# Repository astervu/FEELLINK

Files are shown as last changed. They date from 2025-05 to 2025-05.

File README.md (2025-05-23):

# FEELLINK

LOGO fin

*Met FEELLINK kan een leerling uit een autiklas zijn emoties en gevoelens makkelijk en laagdrempelig communiceren met de leerkracht om zo conflicten, ongemakken en frustraties bij leerlingen in de klas makkelijker te begrijpen en op te lossen. Ook helpt FEELLINK bij zelfregulatie van de leerling door middel van fidgeting en stimming.* 

*Projectteam: Aster Vuylsteke, Aimé Van Alboom*

*Datum: 21/05/2025*

## Samenvatting
Kinderen met ASS hebben vaak moeite om over hun emoties en gevoelens te communiceren. Ze ervaren een hoge drempel om dit te doen of communiceren hun behoeften niet duidelijk, wat kan leiden tot conflicten, ongemak en frustratie.

Om dit probleem te onderzoeken, observeerden we een type 9-klas en voerden we drie interviews uit: met een persoon met ASS, een leerling met ASS en een leerkracht met ervaring in autiklassen. Deze inzichten benadrukten de noodzaak van een laagdrempelig communicatiemiddel dat ook helpt bij zelfregulatie.

Onze oplossing is een slimme fidget met een ingebouwd apparaatje waarmee leerlingen hun emoties kunnen aangeven via iconen (zoals emoji’s). De leerkracht kan in een bijbehorende app de status van elke leerling bekijken.

Het ingebouwde apparaatje maakt communicatie eenvoudiger, omdat de interactie met het apparaat minder confronterend is dan directe mens-mens communicatie. De visuele iconen bevorderen de zelfexpressie en verbeteren het begrip van de eigen emotie bij de leerling. De fidget helpt met zelfregulatie, focus en het verminderen van angst en stress door tactiele stimulatie. Bovendien merkt de omgeving niet dat de leerling iets communiceert, wat extra comfort biedt. Dit zorgt voor een rustigere en meer begripvolle leeromgeving waarin leerlingen beter ondersteund worden.

render feellink !(met knoppen)

## Introductie
Er zijn al verschillende hulpmiddelen beschikbaar die kinderen met autisme spectrum stoornis (ASS) ondersteunen bij het verbeteren van hun communicatieve vaardigheden. Echter, er is nog geen hulpmiddel dat hen direct helpt om hun emoties te identificeren en te communiceren op het moment dat dit nodig is, zonder dat ze een drempel moeten overschrijden die hen kwetsbaar maakt voor de aandacht van andere leerlingen. Dit is vooral problematisch in de klas, waar snel overprikkelde leerlingen vaak niet in staat zijn om effectief te communiceren over hun gevoelens, wat hun welzijn en hun vermogen om zich te concentreren verstoort.

ASS is een spectrumstoornis, wat betekent dat de kenmerken en intensiteit ervan sterk variëren tussen individuen. Veelvoorkomende uitdagingen zijn onder andere moeite met sociale interactie, het herkennen van emoties, en het interpreteren van verbale en non-verbale communicatie. Deze moeilijkheden kunnen leiden tot conflicten in de klas, vaak ontstaan door miscommunicatie of zelfs geen communicatie tussen leerlingen of tussen leerlingen en leerkrachten. Dit kan resulteren in verloren tijd tijdens de les of verminderde prestaties, doordat de leerling zich ongemakkelijk en onbegrepen voelt.

Dit onderzoek richt zich op de ontwikkeling van een product dat kinderen met ASS helpt bij drie cruciale aspecten: communicatie, emotionele regulatie en focus. Het doel is een oplossing te bieden die hen helpt hun emoties op een toegankelijke manier te uiten, zonder dat dit extra stress veroorzaakt. Door dit hulpmiddel te integreren in de klas kunnen misverstanden worden verminderd, kunnen leerlingen zich beter concentreren en kunnen conflicten sneller worden opgelost, wat uiteindelijk bijdraagt aan een effectievere leerervaring.

## Methodologie
Doorheen het ontwerpproces hebben we gewerkt met een gestructureerde aanpak die steeds de gebruiker centraal stelde in het ontwerpproces. Zo hebben we zoveel mogelijk de gebruikersdoelgroep aangesproken om hen te betrekken in het ontwerpproces. Ook konden we zo het product zo gebruikersvriendelijk mogelijk maken.

In de exploratiefase zijn we eerst en vooral begonnen met onderzoek naar de gebruiker. Aangezien de gebruikers vaak specifieke noden kunnen hebben, was het belangrijk om te gaan onderzoeken waar gebruikers veel belang aan hechten. Hiermee ging gepaard dat we een goed doordachte identificatie van het probleem opstelden alsook de analyse ervan. Dit deden we aan de hand van literatuuronderzoek, gebruiker interviews, expert interviews en een ‘day in the life’.  Het ondervonden probleem is dan verder onderzocht geweest, dit aan de hand van literatuuronderzoek en benchmarking over bestaande systemen die men gebruikt bij kinderen met ASS.

In de definitiefase vertrokken we vanuit een storyboard om ons te verdiepen in de noden van de gebruiker. In deze fase hebben we zowel fysieke als digitale prototypes gemaakt die we getest hebben bij onze gebruikersdoelgroep in 3 design waves. Zo moesten we het concept opsplitsen in twee delen met twee verschillende gebruikers, de leerling en de leerkracht. De eerste 2 design waves hebben we besteed aan het zo goed mogelijk voldoen aan de eisen en noden van de leerling. Dit deden we aan de hand van usertesting en userinterviews tijdens deze test om hun eerlijke mening te krijgen. Voor het tweede deel van het concept, de tool voor de leerkrachten, hebben we een enquête gemaakt om insteek te krijgen van de leerkrachten in het maken van de interface van deze tool. Dit deden we aan de hand van vragen te stellen over low fidelity interfaces die we enkele simpele gebruiksinteracties hadden toegekend.

Hierna is er over gegaan naar developfase 1. In deze fase is er begonnen met het onderzoeken van de integratie van het product in de klas als ook onderzoek naar de ergonomie van het product. Dit is vooral gebeurd aan de hand van A/B testing van prototypes gebaseerd op data uit antropometrische tabellen. Zo kon de plaats van het product in de klas worden vastgelegd en ook de grootte van het product en de grootte van de knoppen op de fysieke interface. Daarnaast is er ook gekeken naar de integratie van het emotieaanduidsysteem tot een product samen met de fidget. Dit is gebeurd aan de hand van een beslissingsmatrix met vooraf opgestelde succescriteria en aan de hand van de verschillende mentale modellen die de leerlingen opbouwden bij enkele conceptschetsen. Ook is er een korte peiling gebeurd om te achterhalen met welke fidgets de kinderen het meest vertrouwd zijn.

In developfase 2 vertrokken we vanuit de vraag het product te optimaliseren vanuit het standpunt van de leerkracht. Dit is gebeurd aan de hand van interviews met leerkrachten waarin er gefocust werd op: de meldingen die de leerkracht zou ontvangen bij emotieverandering, dataopvolging van de leerling, het apparaat waarop de leerkracht de stand van de leerling kan zien en eventuele obstakels die door ons gemist waren. Om deze mogelijke obstakels te identificeren is er gebruik gemaakt van een storyboard. Ook is er onderzocht hoe we het emotieaanduidsysteem kunnen integreren tot een product samen met het fidget systeem, dit gebeurde aan de hand van A/B/C-testing waarna de pro's en cons van de twee favorieten afgewogen werden tegen elkaar. Daarnaast is er ook nog even verder ingepikt op de ergonomietesten uit develop 1, waarbij er maximaal gewichtttesten zijn gebeurd.

In de laatste fase, developfase 3, is er onderzocht hoe ervoor kan gezorgd worden dat de leerlingen de tool willen en blijven gebruiken. Dit is gebeurd aan de hand van theoretische modellen en een beperkte literatuurstudie. Hierna volgde een PESTEL analyse door studenten uit het vak De kennismaatschappij en ICT die vanuit een buitenstaander standpunt feedback en tips gaven. Daarnaast is er ook een co-design test gebeurd met de leerlingen waarbij ze zelf konden beslissen in welke volgorde de emotieknoppen moeten staan op de interface. In deze fase is er ook een lessimulatie met een (zo goed als) werkend prototype gebeurd. Hierbij werd er gekeken naar de user experience bij verschillende feedbackmethoden. Om daarnaast ook de algemene integratie in de klas te simuleren is er gebruik gemaakt van Wizard of Oz-testing, waarbij telkens als de leerling een emotie aanduidde, deze werd veranderd op een gedeelde interface met de leerkracht en de leerkracht dan een trilling kreeg doorgestuurd. Na deze simulatie kregen de leerlingen en de leerkrachten een vragenlijst om de user experience beter te kunnen inschatten.

Na elke testfase werd er een grondige analyse uitgevoerd om de belangrijkste ontwerpvereisten te identificeren. Deze vereisten werden zowel gebruikt als richtlijn doorheen het project maar zijn ook eisen die moeten aangehouden worden bij verdere ontwikkeling van het product.



## Discovery

### Doestellingen
In de discoveryfase onderzoeken we de onderzoeksvraag: Hoe kan de leer- en schoolervaring voor kinderen met autisme aangenamer gemaakt worden? Voordat we deze vraag kunnen beantwoorden moeten we volgende stappen doorlopen:

  <ins>  1.	Onderzoek naar de doelgroep</ins>

Hier gingen we vooral op zoek naar wat het betekent om ASS te hebben, met een specifieke focus op kinderen. Hierdoor krijgen we meer inzicht in hun behoeften en uitdagingen.

   <ins>  2.	Probleemidentificatie en analyse</ins> 

We onderzoeken waar kinderen met ASS de meeste moeite mee hebben in een klasomgeving. Welke activiteiten op school leveren het meeste problemen op en wat heeft dit als gevolg op hun resultaten en schoolervaring? Zijn de kinderen bewust van hun eigen emotie en in welke mate kunnen ze die reguleren of communiceren?

  <ins>  3.	Analyse van bestaande producten/hulpmiddelen</ins> 

We bekijken kritisch welke hulpmiddelen er momenteel beschikbaar zijn voor kinderen met ASS. Hoe helpen deze producten hen? Wat zijn de beperkingen, welke verbeterpunten zien we? Welke elementen zijn interessant om te integreren in ons eigen product?

  <ins>  4.	Onderzoek naar de schoolomgeving</ins> 

Omdat het product in een schoolomgeving zal worden gebruikt is het belangrijk om die grondig te verkennen. We analyseren fysieke beperkingen en praktische aspecten zoals: Past dit op een schoolbank? Hoe ziet het schoolmeubilair eruit? Verplaatsen de kinderen zich vaak van klaslokaal naar klaslokaal? Heeft de leerkracht steeds toegang tot zijn/haar gsm/ laptop? …?

### Materiaal & methoden
1.	Literatuuronderzoek

Tijdens het onderzoek naar de doelgroep werd voornamelijk gebruik gemaakt van online bronnen. Aan de hand van zeven verschillende bronnen werd onderzocht wat het betekent om ASS te hebben.
Voor de analyse van bestaande producten/ hulpmiddelen werden 4 bronnen geraadpleegd. De focus lag daarbij op de vraag: Hoe kan ik de communicatie en sociale interacties vlotter doen verlopen voor kinderen met autisme?

2.	Interviews (N = 6)

Er werden twee kinderen met ASS geïnterviewd om hun ervaringen en gevoelens in een klasomgeving beter te begrijpen. Daarnaast werd ook een leerkracht geïnterviewd die lesgeeft aan kinderen met ASS in het type 9 onderwijs, om het probleem vanuit een ander perspectief te bekijken. Ook werden twee auti-coaches en één therapeut geïnterviewd, waarbij de focus lag op het achterhalen waarom kinderen met ASS mindere emotieherkenning en emotiedeling ervaren. De vragen richtten zich verder op communicatie-uitdagingen, overprikkeling en de mogelijkheden die er op school zijn. 

3.	Benchmarking 

Om te bepalen welke aanpak het beste werkt, werden verschillende benchmarks geanalyseerd. Hierbij werd gekeken naar de werkwijze van andere producten en naar de onderlinge verbanden tussen de benchmarks. De producten die werden onderzocht, kwamen zowel uit de suggesties van de respondenten tijdens de interviews als uit zoekopdrachten op Google.

4.	A day in the life (N = 4)

Om de schoolomgeving grondig te onderzoeken volgden we een dag mee met een auti-klasje van het tweede middelbaar. Er werd vooral gelet op hoe de klas is ingericht, hoe hun dag eruit ziet, hoe de leerlingen zich gedragen in de les, wat de aanpassingen zijn in een auti-klasje, … . Dit biedt meer inzicht in de context waarin het product zal worden gebruikt.

### Resultaten
 
 <ins> 1.	Literatuuronderzoek </ins> 

Uit het onderzoek blijkt dat de kenmerken en intensiteit van ASS variëren per individu, omdat het een spectrumstoornis is. Kinderen met ASS hebben vaak moeite met non-verbale en verbale communicatie, wat sociale interacties bemoeilijkt en het vermogen om zich in te leven of gevoelens te interpreteren beperkt. Dit leidt vaak tot isolatie. Ze hebben ook slechtere emotionele regulatie dan typisch ontwikkelde kinderen, met minder effectieve strategieën om tot rust te komen tijdens stressvolle momenten. Prikkelverwerkingsproblemen zijn een kernsymptoom van ASS, waarbij overprikkeling somberheid of angst kan veroorzaken. Externe prikkels krijgen vaak voorrang boven sociale signalen, wat problemen oplevert met centrale coherentie. Ook hebben ze moeite met vaardigheden die essentieel zijn voor taalontwikkeling, zoals joint attention, social referencing, imitatie en doen-alsof spel.
Enkele aspecten die de communicatie en sociale interacties en het leerproces vlotter doen verlopen voor kinderen met ASS zijn: 

  -	PECS

Het Picture Exchange Communication System helpt kinderen non-verbaal hun wensen en behoeften te uiten met visuele hulpmiddelen zoals afbeeldingen en pictogrammen. Het bevordert sociale vaardigheden, zelfexpressie en draagt bij aan een betere zelfwaardering en onafhankelijkheid.

  -	Mens-robot

Mens-robot interacties zijn eenvoudiger te begrijpen dan mens-mens interacties, wat ze minder complex maakt. Robots zijn duidelijker en voorspelbaarder, waardoor ze minder stress en verwarring veroorzaken bij kinderen met autisme.

  -	Fidgets 

Het is bewezen dat kinderen met autisme profiteren van fidget-toys in een educatieve omgeving. Het helpt met focus, zelfregulatie, vermindering van angst en stress. 

 <ins> 2.	Interviews  </ins> 

Tijdens de interviews konden bepaalde problemen gedefinieerd worden: 
-	Angst om vragen te stellen aan de leerkracht
-	Moeite met confrontaties met medeleerlingen
-	Problemen met het vinden van woorden om gevoelens te uiten
-	Niet weten hoe gevoelens aan de leerkracht over te brengen, wat leidt tot conflicten in de les
-	Leerkrachtentekort door de kleine auti-klassen
-	Leerlingen die goed kunnen uitleggen hoe ze zich voelen, botsen vaak met diegenen die dit niet kunnen

Enkele vereisten die de respondenten ons meegaven:
-	Het product moet stevig zijn omdat leerlingen de neiging hebben om dingen uit elkaar te halen.
-	Het doel van het product moet duidelijk zijn, anders wordt het niet gebruikt.
-	Er moet ruimte zijn voor fouten, aangezien kinderen met ASS impulsief zijn.
-	Het product mag geen geluid maken, om de les niet te verstoren.

> [!IMPORTANT]
> Design requirements:
> - D1.1: Het product moet stevig zijn zodat leerlingen het niet makkelijk uit elkaar kunnen halen.
> - D1.2: Het gebruiksdoel moet duidelijk aangegeven zijn.
> - D1.3: Er moet ruimte zijn voor fouten.
> - D1.4: Het product mag heel weinig tot liefst geen geluid maken.
 
De coaches en therapeut lieten ons weten dat kinderen met ASS vaak niet begrijpen dat anderen hun gevoelens niet automatisch kunnen zien, omdat ze zelf denken dat lichaamstaal genoeg zegt. Dit maakt het moeilijk om sociaal gepast te reageren, vooral wanneer ze emoties verkeerd interpreteren of moeite hebben met het communiceren van hun behoeften. 

Na deze interviews hebben we persona’s aangemaakt voor de mensen die in contact zullen komen met dit product.



 <ins> 3.	Benchmarking  </ins>

Veel bestaande oplossingen gebruiken gezichtsuitdrukkingen om kinderen te helpen emoties aan te duiden. Deze methoden leren hen herkennen hoe ze zich voelen en hoe ze daarop kunnen reageren. Het lijkt nuttig om ook kleuren te gebruiken, zodat kinderen intuïtief het systeem begrijpen zonder dat het extra prikkels geeft tijdens een crisis.



De meeste bestaande producten houden geen rekening met de confrontatie met medeleerlingen, terwijl dit juist een probleem is voor de kinderen.

> [!IMPORTANT]
> Design requirements:
> - D2.1: Bij het aanduiden van emoties moeten kleuren gebruikt worden.
> - D2.2: Het aanduiden van emoties moet anoniem kunnen gebeuren ten opzichte van de medeleerlingen.

<ins> 4.	A day in the life </ins>

Er werd gelet op de fysieke beperkingen van de klas, die meestal klein is en bestaat uit maximaal 6 leerlingen. De tafels en stoelen zijn vaak neutraal beige van kleur, en veel objecten in de klas hebben een kubusvorm. Ook werden praktische aspecten onderzocht: de leerkracht heeft altijd toegang tot een gsm of laptop (de laptop van de leerkracht is echter doorgaans verbonden met het digibord, wat voor moeilijkheden zorgt bij het werken met een app op de laptop). De leerlingen blijven meestal in hetzelfde lokaal.

> [!IMPORTANT]
> Design requirements:
> - D1.5: Het product moet kubusvormig zijn en moet een neutrale kleur hebben om goed in het klasbeeld te blenden.
> - D3.1: De app mag niet zichtbaar zijn op de laptop wanneer verbonden met digibord/beamer.

### Conclusies & implicaties

Belangrijkste inzichten
-	Het niet kunnen herkennen en communiceren van emoties is het kernprobleem, wat leidt tot miscommunicatie en sociale conflicten. Dit wordt versterkt doordat kinderen met ASS sneller overprikkeld raken, vooral na speeltijden of groepsactiviteiten, waardoor ze extra prikkelbaar zijn.
-	Er is behoefte aan:
    -	duidelijkheid: Zonder een duidelijk doel zal het product niet gebruikt worden. 
 	  -	herkenbaarheid: Hierdoor voelt het kind zich vertrouwd met het product zonder dat het overprikkeld raakt door verwarrende elementen of onverwachte veranderingen.
    -	ruimte voor fouten: De impulsiviteit van kinderen met ASS maakt het belangrijk om hen een kans te geven om te experimenteren met het product zonder dat ze stress krijgen om fouten te maken.

Design implicaties 
-	Visuele hulpmiddelen zoals pictogrammen, gezichtsuitdrukkingen en kleurencodes die emoties herkenbaar maken.
-	Om de emotionele regulatie en focus te optimaliseren kunnen fidgets een behulpzame maar secundaire tool in het ontwerp zijn.
-	Een applicatie voor de leerkracht die overzicht biedt over de gevoelens van alle leerlingen zodat ze kunnen inspringen op de emotionele behoeften van het kind.

> [!IMPORTANT]
> Design requirements:
> - D2.3: Bij het aanduiden van emoties moeten gezichtsuitdrukkingen gebruikt worden.

## Definition
In de definition fase is er gedefinieerd wat de oplossingen zijn die we kunnen gebruiken voor het gevonden probleem. Hierbij hebben we het oog gelegd op de gebruiker en zijn nood, zonder assumpties te maken over deze gebruiker. Dit is gebeurd aan de hand van 3 prototyping/design waves die elk focusten op bepaalde aspecten van het ontwerp concept.

### Doestellingen
De algemene doelstelling is een helder gedefinieerd finaal ontwerpconcept. 

WAVE 1: In de eerste wave willen we achterhalen op welke manier we het best de kinderen hun emoties laten aanduiden. Daarnaast willen we ook testen of gebruik van kleur het aanduiden van emoties kan bevorderen en welke kleur de kinderen associëren met welke emotie.

WAVE 2: In de tweede wave zullen we voortbouwen op de eerste wave, hierin zullen we al iets meer gespecifieerd te werk gaan om de testpool te vergroten en duidelijkere verbanden te vinden. Ook zullen we in deze tweede wave testen welke materialen geschikt zijn voor het maken van de fidgettoy. 

WAVE 3: Het doel van de derde wave is om te definiëren hoe we de interface van de leerkracht optimaal kunnen ontwerpen.

### Materiaal & methoden
-	touch and feel board
-	quick and dirty prototypen
-	digitaal ontworpen interfaces
-	gebruikersinterviews
-	gebruikerstesten
- enquête

### Resultaten

<ins> WAVE 1 (N = 4) </ins>

Op basis van benchmarks zijn er verschillende oplossingen geprototyped om emoties aan te duiden. Namelijk de emotieradar, emotiedraaiknop, emotiedraairad, emotieschuifknop en emotieknoppen. Aan de hand van verschillende verhalen waarin het kind zich moest inleven, moest het kind aanduiden op deze verschillende prototypes hoe de persoon in het verhaal zich voelde. Hierbij keken we hoe gemakkelijk dat het kind de emoties kon aanduiden en stelden hen ook enkele vragen omtrent de gebruikservaring en hun mening over wat ze het beste vonden en waarom ze dit vonden.



Daarna kreeg het kind een blaadje met emoticons van de verschillende gebruikte emoties. Deze konden ze inkleuren in de kleuren die zij associëren met de emoties. Hierna hebben we opnieuw verhaaltjes verteld waarin ze zich moesten inleven. Hierbij hebben we vooral gelet op de invloed van de kleuren op het gebruiksgemak en de gebruiksvriendelijkheid. 




<ins> WAVE 2 (N = 10)</ins>

In wave 1 hebben we bepaalde ontwerpen voor het aanduiden van emoties kunnen elimineren waardoor we nu iets gerichter konden tewerk gaan. We gaan op dezelfde manier te werk, maar nu op een andere school, als in wave 1 maar deze keer maken we het uitdagender om een specifieke emotie te identificeren door de scenario’s complexer en gedetailleerder te maken. Op deze manier kunnen we elk prototype grondig testen en de grenzen van hun effectiviteit evalueren. 



Daarnaast vroegen we ook opnieuw om de emoticons in te kleuren zodat we een grotere databank hadden aan gekleurde emoticons om beter verbanden te leggen tussen de kleurassociaties. Hierbij is de kleur van de emotie vastgelegd op de kleur die het meest aan bod kwam. 



Ook is er gekeken naar toevoeging van vraag en hulpfunctie: ‘ik wil mijn hand opsteken’ en ‘ik heb hulp nodig’. We hebben verschillende prototypes ontwikkeld die verschillende manieren voorstellen om deze functies aan te geven. Tijdens de test vragen we de leerlingen om de prototypes uit te proberen en beantwoorden ze enkele vragen om hun ervaringen en voorkeuren beter te begrijpen.



Omdat personen met ASS makkelijker overprikkeld geraken is het sensorische aspect van ons product heel belangrijk. Daarom hebben we ons in deze wave ook nog gefocust op het ervaren van verschillende texturen met een touch and feel bord.  Hierbij hebben we de leerling blindelings laten voelen aan de materialen en hun vragen gesteld over wat ze aangenaam vonden en minder aangenaam vonden om aan te voelen zodat we hierop het materiaal van het product kunnen baseren. We deden dit hierna ook eens opnieuw zonder het wegnemen van het visuele zintuig om zo dit zintuig een minimale tot geen invloed te geven.



<ins> WAVE 3 (N = 6) </ins>

Bij deze wave zijn we ons gaan focussen op het deel van het concept dat betrekking heeft op gebruik door de leerkracht. Namelijk de interface van de tool die door de leerkracht kan worden gebruikt. Hierbij hebben we een enquête opgesteld. Om de app intuïtief te maken voor de leerkracht, vragen we ook welke apps zij vaak gebruiken in een schoolse context. Hierdoor kunnen we bepaalde lay-outs, symbolen en kleurencombinaties overwegen om te gebruiken in de finale interface.

In de enquête zullen we ook verschillende ontwerpvoorstellen doen. Enerzijds voor een overzichtscherm, waar we polsen naar de overzichtelijkheid en wat er eventueel kan toegevoegd worden.



Anderzijds ook voor een emotiescherm, hier hebben we 9 schermen van. We polsen opnieuw naar de overzichtelijkheid en wat er kan toegevoegd en verbeterd worden. Er werd gevraagd naar een top 3 van favorieten en niet-preferente. De resultaten van de samengestelde top 3’s werden verwerkt in een scoringsmatrix. Prototypes die op de eerste plaats stonden, kregen +3 punten, terwijl de tweede en derde plaatsen respectievelijk +2 en +1 punten opleverden. Prototypes waarvoor deelnemers een afkeur uitten, kregen -1 punt. Door de scores van alle deelnemers per interface op te tellen, werd een eindscore bepaald. 




Hierna werd er ook nog gepolst naar de positieve en negatieve punten van een interface voor een leerlingpaneel. Alsook naar wat er eventueel nog aan kan verbeterd worden.


### Conclusies & implicaties
Uit wave 1 concluderen we dat de emotiedraaiknop en het emotiedraairad niet geschikt waren voor het aanduiden van emoties, dit omdat we hadden opgemerkt dat de kinderen er vaak mee prutsten en ronddraaiden tijdens dat ze nadachten over het antwoord. Dit wil wel zeggen dat het ideaal is als fidgeting element op het eindconcept.

Daarnaast zagen we dat het gebruik van kleur het gebruiksgemak weinig beïnvloed, we hebben wel gekozen om verder te gaan op het gebruik van kleur omdat dit het gebruik iets aangenamer kan maken. Omdat er nog geen duidelijke verbanden gevonden waren in de kleuren besloten we de testpool te vergroten en dit ook in wave 2 te doen.

> [!IMPORTANT]
> Design requirements:
> - D1.6: Er moet een draaiend fidgeting element aanwezig zijn.

In wave 2 hebben we voor het emotieaanduidsysteem gekozen voor het drukknoppensysteem. Ook al was dit niet het populairst toch hebben we besloten om deze te nemen. Dit omdat we merkten dat de nood om verschillende emoties aan te duiden groot was. Op de emotieradar en emotieslider kon je wel verschillende emoties aanduiden maar werd je steeds beperkt doordat je enkel combinaties kon maken van emoties die naast elkaar lagen georiënteerd op het product. Bij het gekozen drukknopsysteem zouden we wel een bevestigingsknop toevoegen, zo kunnen de leerlingen meerdere emoties aanduiden en dan bevestigen. Dit zorgt ook voor een extra staps verificatie waardoor de angst om fouten te maken kleiner zal zijn voor de leerling.

Voor de vraag en hulpfunctie hebben we besloten om te werken met knoppen. Dit aangezien onze testgroep een schuifknop niet zo duidelijk vond. Omdat het verschil tussen de twee functies (‘ik wil mijn hand opsteken’ en ‘ik heb hulp nodig’) vaak als niet zo duidelijk werd ervaren is er nu ook gekozen om één knop te voorzien voor beide functies. Deze knop heeft een vraagteken aangezien de leerlingen het handje van ‘hand in de lucht steken’ associeerden met STOP.

Bij de kleurassociaties hebben we besloten de 7 emoties te vereenvoudigen naar 6 emoties aangezien we merkten dat de kinderen het verschil niet wisten tussen de 2 gradaties van verdriet, en ook willen we het symbool van gefrustreerd aanpassen aangezien dit vaak voor verwarring zorgde.

Uit de kleurassociaties zijn volgende verbanden gekomen: verdriet = blauw, blij = geel, boos = rood, verbaasd = roze, neutraal = oranje , verward = bruin.



Uit de gebruikerstesten met het touch and feel board zijn we tot de conclusie gekomen dat we gaan gebruikmaken van het materiaal waaruit de dogbone is gemaakt, namelijk thermoplastische rubber. Ook al was de topfavoriet de middelste textuurmat. Dit aangezien de reden voor het kiezen van de middelste textuurmat vaak was dat het lichtjes indrukbaar was zoals computertoetsen en we dachten dat dit beter zou zijn als fidgeting element op het eindconcept.

> [!IMPORTANT]
> Design requirements:
> - D1.7: De buitenkant van het product moet gemaakt zijn van thermoplastische rubber.
> - D1.8: Er moet een element zijn op het product met dezelfde kenmerken van indrukbaarheid als de ‘middelste textuurmat’ van het touch and feel board.
> - D2.4: Je moet meerdere verschillende emoties tegelijk kunnen aanduiden.
> - D2.5: De emoties moeten zo simpel mogelijk gehouden worden.
> - D2.6: De emoties moeten aangeduid kunnen worden aan de hand van verschillende knoppen.
> - D2.7: Er moet een bevestigingsknop zijn om de error proofness te vergroten.
> - D2.8: Er moet een knop aanwezig zijn met een vraagteken en die betekent dat er een vraag is en er een leerkracht moet komen.
> - D2.9: De emotie-kleur verdeling moet zijn: verdriet = blauw, blij = geel, boos = rood, verbaasd = roze, neutraal = oranje , verward = bruin.

De grote besluiten uit wave 3 hebben we nog niet genomen, dit aangezien we nog net iets te weinig testpersonen de enquête hebben kunnen laten invullen. We zouden hier later nog eens op terug komen om het nog beter uit te werken en meer focus te leggen op het standpunt van de leerkracht zelf om het product vanuit zijn/haar kant ook te optimaliseren. Er zijn wel enkele suggesties verkregen en ook zijn er enkele zaken opgevallen die zeker nuttig kunnen zijn voor de volgende ontwerpfase. Zo kan er bij de volgende ontwerpfase eens naar de verschillende aangehaalde leerkrachtentools gekeken worden om inspiratie te halen voor verschillende functies en handelingen. Daarnaast is bij het emotiescherm ook bevestigd dat werken met emoticons en kleuren ook vanuit het standpunt van de leerkrachten, die er dagelijks mee in contact komen, een goed idee lijkt. Dit bleek namelijk uit de decision matrix die opgesteld werd waarbij we zagen dat de favorieten en commentaren steeds deze richting uitwezen.



Verdere analyse is te vinden in het report hiervan ([report wave 3]([url](https://ugentbe-my.sharepoint.com/:w:/g/personal/aster_vuylsteke_ugent_be/ETFXeHp6ypxMi6rCLQbqeeABHassiN-m-b7oYoHdmw8uig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)))

## Develop 1
### Doelstellingen

In de eerste develop fase wilden we volgende 4 onderzoeksvragen behandelen:
1.	Hoe wordt het product in de klas geïntegreerd?
2.	Hoe kunnen we ons product zo ergonomisch mogelijk maken?
3.	Hoe kunnen we het emotieaanduidsysteem integreren tot een product samen met het fidget systeem?
4.	Welke soorten fidgets kunnen we integreren in de tool?
5.	Wat is diepe druk? + Hoe helpt diepe druk kinderen met autisme? + Hoe kunnen we dit integreren in de FEELLINK?

### Materiaal & methoden 
- antropometrische data
- gelasercutte kubussen
- interfaces met magnetisch verwisselbare knoppen
- A/B testing
- mentale modellen
- sticky dot voting bij conceptschetsen
- beslissingsmatrix met succescriteria
- peiling
- desk research

### Resultaten
<ins> Onderzoeksvraag 1: Hoe wordt het product in de klas geïntegreerd? </ins>

Om de optimale plaatsing van de fidget in de klas te bepalen, beperken we ons tot de persoonlijke bank en stoel van elke leerling, zodat de fidget altijd beschikbaar is. We testen verschillende locaties, zoals de hoek van de bank, onderaan de stoel, aan de zijkant van de bank/stoel,... . Leerlingen proberen een prototype op een van deze plaatsen te grijpen, waarna we observeren hoe vlot en onopvallend dit gebeurt. Vervolgens kiezen ze hun twee voorkeurslocaties en lichten ze hun keuze toe. Tot slot voeren we A/B-testing uit om de beste optie te bepalen op basis van de voor- en nadelen van beide voorkeursplaatsen.

<ins> Onderzoeksvraag 2: Hoe kunnen me ons product zo ergonomisch mogelijk maken? </ins>

Om de ergonomie van het product te optimaliseren, focussen we op twee aspecten: de grootte van de kubus en de knoppen. We passen “design for the mean” toe en baseren ons op antropometrische data van 13-jarige kinderen. Voor de kubusbreedte gebruiken we de gemiddelde handbreedte (79 mm) als referentie en testen dit met vijf kubussen (60, 70, 79, 90 en 100 mm). Leerlingen krijgen deze in willekeurige volgorde en simuleren gebruik via situatieschetsen. Ze geven vervolgens hun voorkeur en motivatie aan.

groottes prototypes

Voor de knoppen testen we drie diameters (10, 15 en 20 mm), omdat er geen geschikte antropometrische data beschikbaar was. Via A/B-testing vergelijken leerlingen twee interfaces en benoemen de voor- en nadelen. Om de test interactiever en leuker te maken, laten we hen in de rol van ontwerper stappen. Ze creëren zelf een interface met verschillende knopgroottes en ordeningen, waarna we hun keuzes en redeneringen bespreken.

interface 1
interface2

<ins> Onderzoeksvraag 3: Hoe kunnen we het emotieaanduidsysteem integreren tot een product samen met het fidget systeem?  </ins>

Om het fidget- en communicatiegedeelte te scheiden, presenteren we verschillende conceptschetsen aan leerlingen. Elk concept wordt afzonderlijk getoond, waarbij we vragen stellen over hun interpretatie en associaties. Dit helpt ons inzicht te krijgen in hun mentale modellen en mogelijke metaforen. Vervolgens stemmen de leerlingen met sticky dot voting op hun favoriete concept. De verzamelde inzichten worden gecombineerd met een beslissingsmatrix om het ideale combineersysteem te bepalen.

De succescriteria voor de gewogen beslissingsmatrix is de volgende:
1. duidelijke scheiding tussen de functies (gewicht=5)
2.	intuïtief gebruik (gewicht = 3)
3.	makkelijke handeling (gewicht = 4)
4.	doel snel bereiken (gewicht = 1)
5.	voelt niet aan als fidget (gewicht = 2)
6.	childproof (gewicht = 3)
7.	kinderen vinden het een handig systeem (sticky dot voting) (gewicht = 5)

De voorgestelde concepten zijn de onderstaande schetsen:

a. 
  
b. 

c. 

d. 

e. 

f. 

Hieruit konden we de volgende gewogen beslissingsmatrix opstellen:

gewogen beslissingsmatrix

<ins> Onderzoeksvraag 4: Welke soorten fidgets kunnen we integreren in de tool?  </ins>

Om een beter inzicht te krijgen in geschikte fidgets voor de fidgetfunctie, vroegen we leerlingen naar hun ervaring en voorkeuren. We peilden of ze zelf fidgets gebruiken, welke hun favoriet is, welke fidgets ze vaak in de klas zien en welke hun vrienden gebruiken.

<ins> Onderzoeksvraag 5: Wat is diepe druk? + Hoe helpt het kinderen met autisme? + Hoe kunnen we dit integreren in de FEELLINK?  </ins>

Na het analyseren van de resultaten van onderzoeksvraag 4 viel op dat veel kinderen aangaven rustiger te worden wanneer ze in iets kunnen knijpen. Dit effect is gelinkt aan een vorm van sensorische therapie, namelijk diepe druk. Om te evalueren of dit principe geïntegreerd kan worden in de tool, werd hierover verder onderzoek gedaan.

### Conclusies & implicaties
Uit de testen van onderzoeksvraag 1 konden we door observatie en de voorkeuren van de leerlingen concluderen dat de hoek van de bank de ideale plek is voor de tool. Deze locatie is het meest comfortabel, omdat leerlingen geen onnatuurlijke beweging hoeven te maken om de tool te pakken. Bovendien is de beweging subtiel, waardoor ze geen ongewenste aandacht van klasgenoten trekken. Het terugplaatsen verloopt eveneens probleemloos, aangezien er geen vaste positie of opzetstuk nodig is. Hierdoor kunnen leerlingen de tool moeiteloos gebruiken zonder er veel aandacht aan te besteden.

> [!IMPORTANT]
> Design requirements:
> - D1.9: De plaats van de tool in de klas is op de persoonlijke bank van de leerlingen.

Bij de testen van de grootte van de kubus werd de ideale maat vastgesteld op 79 mm, wat overeenkomt met de gemiddelde handpalmgrootte van 13-jarigen. Alle leerlingen konden deze afmeting vlot hanteren, wat ook bleek uit de stemming. 

Een grotere kubus zou het fidgeten bemoeilijken, vooral na langdurig gebruik. Fidgeting duurt doorgaans langer dan simpelweg een knop indrukken, en een grotere tool zou oncomfortabel worden om vast te houden, wat de effectiviteit en het plezier zou verminderen. Bij een kleinere afmeting merkten we dat leerlingen hun hele hand over de tool moesten bewegen, wat de precisie en het gebruiksgemak verminderde. Daarom kiezen we voor de middenweg van 79 mm, die zowel comfort als functionaliteit biedt, gebaseerd op de antropometrische tabellen.

Uit observatie en feedback bleek dat knoppen van 20 mm diameter het meest geprefereerd werden. We kunnen ook afleiden dat alle knoppen dezelfde grootte moeten hebben, aangezien de helft van de leerlingen geen voorkeur had, terwijl de andere helft dit wel belangrijk vond. Bij het ontwerpen van de finale interface zorgen we ervoor dat de knoppen voldoende afstand van elkaar hebben, zodat de juiste knop gemakkelijk ingedrukt kan worden. Daarnaast plaatsen we de meest gebruikte knoppen dichter bij de duimen en vingers van de kinderen.

knop1
knop2
knop3
knop4

> [!IMPORTANT]
> Design requirements:
> - D4.1: De grootte van de tool (kubus) is 79 cm.
> - D4.2: De knoppen op de fysieke interface moeten een diameter hebben van 20 mm.
> - D4.3: De knoppen op de fysieke interface moeten allemaal dezelfde grootte hebben.
> - D4.4: De knoppen op de fysieke interface moeten voldoende ver van elkaar gespreid zijn en dus niet vlak naast elkaar staan.
> - D4.5: De door de leerlingen het meest gebruikte knoppen moeten het makkelijkst bereikbaar zijn binnen de range of motion van de duimen.

Uit de bevindingen van onderzoeksvraag 3 bleek dat de schuif en de knop als favorieten naar voren kwamen uit de keuzematrix met succescriteria. De mentale modellen van de kinderen toonden aan dat deze concepten het beste aansloten bij onze visie: de lade deed denken aan een bureau, terwijl de knop associaties opriep met een aan-/uitknop van een elektrisch apparaat. De link met een elektrisch toestel zou er bovendien voor zorgen dat de tool minder snel mishandeld wordt (ermee gooien, stuk maken).
Toch hebben we, omdat communicatie de kern van ons concept vormt en fidgeting een secundaire functie is, besloten de schuif te schrappen en ons te concentreren op de knop. We nemen dit concept mee naar de volgende fasen voor verdere tests en optimalisatie.

sticky dot

> [!IMPORTANT]
> Design requirements:
> - D1.10: De fysieke interface moet lichtjes bevatten die aantonen dat de knoppen aanstaan en werken.

Uit de antwoorden van het interview over fidgets blijkt dat de meest gebruikte fidgets op de school tangles en stressballen zijn. Beide fidgets liggen goed in de hand, kunnen met één hand gebruikt worden en bieden de mogelijkheid om druk uit te oefenen, wat bijdraagt aan kalmering. Deze druk stimuleert diepe drukstimulatie, die helpt bij zelfregulatie en prikkelverwerking in de hersenen. We besluiten verder onderzoek te doen naar deze bevindingen.

> [!IMPORTANT]
> Design requirements:
> - D1.11: De leerlingen moeten in de fidget kunnen knijpen zonder zichzelf pijn te doen en zonder de tool kapot te maken.

 <ins> 1.	Desk research  </ins> 

1. Wat is diepe druk?
   
Diepe druk therapie is een sensorische methode die vaak wordt ingezet bij kinderen met autisme. Ze geeft het lichaam stevige tactiele prikkels en proprioceptieve input via bijvoorbeeld knuffels, omhelzingen of het knijpen in voorwerpen zoals stressballen.

2. Hoe helpt diepe druk kinderen met autisme?

Diepe druk therapie beïnvloedt het autonome zenuwstelsel door stress te verminderen en ontspanning te bevorderen. Het verlaagt de activiteit van het sympathisch zenuwstelsel en verhoogt die van het parasympathisch systeem, wat leidt tot een rustiger hartslag, diepere ademhaling en minder cortisol. Daarnaast verhoogt het de aanmaak van serotonine en dopamine, wat bijdraagt aan een beter humeur en meer ontspanning. Bij kinderen met ASS kan diepe druk stress verlagen, de stemming verbeteren, de focus verhogen en het gedrag positief beïnvloeden. Het effect verschilt per kind, dus het is belangrijk om de toepassing af te stemmen op hun individuele sensorische voorkeuren.

3. Hoe wordt dit toegepast op de tool?
   
De onderzochte effecten van diepe druk zijn voornamelijk gebaseerd op toepassingen over het volledige lichaam, zoals massages of omhullende druk. Bij gebruik van de FEELLINK gaat het echter om lokale druk in de handpalm, op momenten waarop de gebruiker daar zelf behoefte aan heeft. Hierdoor worden mildere, maar vergelijkbare effecten verwacht.
Om diepe druk correct te integreren in de tool, is het belangrijk dat de FEELLINK bestand is tegen knijpen zonder te breken of pijn te veroorzaken. Dit kan worden gerealiseerd door gebruik te maken van zachte en ductiele materialen.

## Develop 2
### Doelstellingen

In de eerste develop fase wilden we volgende 3 onderzoeksvragen behandelen:
1.	Hoe kunnen we ons product optimaliseren vanuit het standpunt van de leerkracht?
2.	Hoe kunnen we het emotieaanduidsysteem integreren tot een product samen met het fidget systeem?
3.	Hoe kunnen we ons product zo ergonomisch mogelijk maken?

### Materiaal en methoden
- prototype met fidgets
- prototype met open kant
- storyboard met de leerkracht als hoofdrol
- weegschaal
- verschillende soorten knoppen
- interview
- gewichtstesten
- A/B/C-testen
- pro's en cons afweging
- e-prototype

### Resultaten
<ins> Onderzoeksvraag 1: Hoe kunnen we ons product optimaliseren vanuit het standpunt van de leerkracht? </ins>

Om te onderzoeken hoe leerkrachten het best ondersteund kunnen worden bij het ontvangen van de signalen die leerlingen via FEELLINK doorgeven, zullen we een interview afnemen. 
Tijdens het interview focussen we ons op:
- voorkeur van ontvangen meldingen
- dataopvolging
- voorkeur van apparaat
- gradatie in meldingen (welke zijn belangrijker)
- obstakels
- ...

Om mogelijke obstakels te identificeren die wij zelf over het hoofd zouden kunnen zien, hebben we een storyboard opgesteld waarin de leerkracht de hoofdrol speelt. Tijdens het interview overlopen we dit storyboard samen met de leerkracht en vragen we hen om feedback te geven bij elk moment waarop zij mogelijke obstakels of knelpunten opmerken.

storyboard leerkracht

<ins> Onderzoeksvraag 2: Hoe kunnen we het emotieaanduidsysteem integreren tot een product samen met het fidget systeem? </ins>

In een vorige developfase hebben we het concept van een knop onderzocht, maar daarbij kwamen enkele twijfels naar voren: zorgt de knop voor voldoende onderscheid tussen functies, en wordt de interface niet te druk met meerdere knoppen?
Om dit verder te verfijnen, testen we nu verschillende alternatieven voor de knop die zowel visueel als functioneel beter onderscheid bieden. We beperken ons tot een selectie van mogelijke bedieningsvormen:
- joystick
- schuifknop
- draaiknop
  
joystick
switch
draaiknop

Voor de test bouwen we één flexibel prototype waarop we eenvoudig de verschillende knoppen kunnen uitwisselen. We integreren ook fidgets in dit prototype, zodat het volledige concept wordt meegenomen in de beleving. Tijdens de test vertellen we de kinderen verhaaltjes over een fictieve leerling, zodat zij via speelse interactie met de tool kunnen aangeven wat voor hen het prettigst werkt. Zo verkrijgen we gerichte feedback over zowel de gebruiksvriendelijkheid als de voorkeur voor een bepaald type knop.
We werken met e-prototypes die gebruikmaken van Arduino om zowel visuele (lichtjes) als haptische (trilling) feedback te geven bij het aan- en uitzetten van de knop. Dit laat ons toe om de effectiviteit en voorkeur voor beide feedbackvormen nauwkeurig te vergelijken.

develop 2 foto

<ins> Onderzoeksvraag 3: Hoe kunnen we ons product zo ergonomisch mogelijk maken? </ins>

Omdat het product tijdens gebruik in de hand wordt gehouden, is het gewicht cruciaal voor de gebruiksvriendelijkheid. Om te voorkomen dat het ontwerp te zwaar wordt, willen we een duidelijke grenswaarde bepalen.

Hiervoor gebruiken we het prototype met de juiste afmetingen uit de groottetest. We voegen geleidelijk gewicht toe en laten kinderen de normale handelingen uitvoeren met de tool. Zo observeren we wanneer vermoeidheid of ongemak optreedt.

Daarnaast testen we hoelang ze het prototype comfortabel met één hand kunnen vasthouden. We laten hen het prototype vijf minuten vasthouden en noteren vanaf welk moment het als te zwaar wordt ervaren.

Tot slot beoordelen we ook of extra gewicht de controle en grip op het product negatief beïnvloedt. Op basis van deze observaties bepalen we de maximale toelaatbare gewichtsklasse voor het uiteindelijke ontwerp.

gebruikerstest foto

### Conclusies & implicaties

Uit de interviews konden er enkele design requirements geconcludeerd worden, om ons product te optimaliseren vanuit het standpunt van de leerkracht. Deze kwamen voort uit de suggesties van de geïnterviewde leerkrachten voor de app/interface/tool van de leerkrachten:

> [!IMPORTANT]
> Design requirements:
> - D3.2: We moeten werken met dezelfde kleuren + emojis als van de FEELLINK.
> - D3.3: De leerkrachten krijgen in real-time de meldingen binnen.
> - D3.4: Het moet een mogelijkheid zijn om een gast toe te kunnen voegen bij het co-teachen of als er hulp moet ingeschakeld worden.
> - D3.5: Bij de emotie blij hoeft er geen melding gegeven worden.
> - D3.6: De interface mag niet gekoppeld worden aan de gsm (privé niet koppelen aan werk).
> - D3.7: Een stille trilling is een ideale manier om een melding te ontvangen.
> - D3.8: Het bijhouden van de data in een weekoverzicht per leerling is handig voor de klassenraden.
> - D3.9: Er moet een optie zijn om de meldingen voor een bepaalde periode te snoozen (na de bepaalde periode zullen de meldingen automatisch ingeschakeld zijn)
> - D3.10: De leerkracht krijgt enkel meldingen als die lesgeeft aan de klas.

Bij het bespreken van de testresultaten van onderzoeksvraag 2 blijkt al snel dat de draaiknop geëlimineerd kan worden: ze is niet intuïtief, aangezien sommige kinderen probeerden te duwen of te trekken in plaats van te draaien.
De voordelen en nadelen van de joystick en switch zijn als volgt:

Joystick:

+++ Herkenbaar en goed van formaat

--- Wordt vaak gebruikt als fidget, klikgeluid is storend

Switch:

+++ Intuïtief, makkelijk te gebruiken, doet denken aan een lichtknop (mentaal model; men zal hier minder mee prutsen)

--- Te klein

Er is een duidelijke voorkeur voor visuele feedback. Eén kind gaf wel aan dat hij liever niet heeft dat anderen zien dat de FEELLINK aanstaat. Een combinatie van een subtiel lichtje met een aanduiding bij de knop is dus een goede oplossing. 

Uiteindelijk kiezen we voor de switch als aan/uit-knop, op voorwaarde dat ze groter wordt gemaakt.
Voor de feedback combineren we een verlichte knop met een visuele aanduiding rond de knop voor subtiele maar duidelijke terugkoppeling.

> [!IMPORTANT]
> Design requirements:
> - D1.12: De aan/uit knop is een switchknop die groter is dan 9x4 mm.
> - D1.13: De feedback op het aan- /uitzetten van de FEELLINK moet visueel maar subtiel zijn (=een verlichte bevestigingsknop + aanduiding bij de knop)

Uit de testen omtrent onderzoeksvraag 3 kan er geconcludeerd worden dat 200g een goede grenswaarde is voor het gewicht van de tool. Dit is een goede grenswaarde aangezien een smartphone gemiddeld ook 200g weegt wat relevant is aangezien een smartphone vaak langer dan 5 minuten met 1 hand wordt vastgehouden.

> [!IMPORTANT]
> Design requirements:
> - D4.6: Het maximaal gewicht van de tool is 200g.

## Develop 3
### Doelstellingen

1. Hoe zorgen we ervoor dat de leerlingen de tool willen en blijven gebruiken?
2. PESTEL-analyse
3. Hoe kunnen we de user experience nog optimaliseren?

### Materiaal en methoden
- theoretische modellen
- beknopte literatuurstudie
- PESTEL analyse
- lessimulatie
- werkende prototypes
- Wizard of Oz-testing
- leerkracht interface
- vragenlijst
- PESTEL-analyse dankzij studenten vak De kennismaatschappij en ICT
- co-design with children

### Resultaten
<ins> Onderzoeksvraag 1: Hoe zorgen we ervoor dat de leerlingen de tool willen en blijven gebruiken? </ins>

We vinden deze onderzoeksvraag belangrijk, omdat het effect van de tool afhangt van het gebruik ervan. Kinderen met autisme staan vaak terughoudend tegenover veranderingen, dus de tool mag zeker niet als verplicht aanvoelen. Om beter te begrijpen wat het gebruik stimuleert, baseren we ons op twee modellen.

1. HOOK MODEL
   
Het Hook-model zorgt ervoor dat het gebruik van de Feellink een herhalende cyclus wordt, wat leidt tot gewoontevorming. Dit is belangrijk voor kinderen met ASS, omdat vaste patronen voorspelbaarheid en structuur bieden. Hierdoor voelen ze zich veiliger, ervaren ze minder stress en kunnen ze beter zelfreguleren. De gevormde gewoonte stimuleert bovendien dat het kind de tool blijft gebruiken.

HOOK MODEL

We passen het model toe op zowel het communicatiegedeelte als het fidgetgedeelte.

COMMUNICATIEGEDEELTE 
-	Interne trigger: het gevoel dat ze op dat moment ervaren
-	Action: de tool in communicatiemodus zetten, de emotieknop indrukken
-	Variable reward; je gevoel wordt erkend door de leerkracht
  
    Reward of the tribe = Sociale beloningen die gedreven zijn door samenhorigheid met anderen. Het maakt ons geaccepteerd, aantrekkelijk, belangrijk en inbegrepen voelen. Als je iemand anders ziet beloond worden wil je dit ook (social learning).
 	
    Brainstorming:
 	
    - er is een streak gelinkt aan het gebruik
    - ze krijgen muntjes bij gebruik die ze kunnen gebruiken om een karakter mee aan te kleden op een app
    - als ze de tool gebruikt hebben gaat de meter op bord omhoog op het einde van de dag, gezamelijke mijlpaal op het klasdashbord
      
  -	Investment: …

FIDGETGEDEELTE 
-	Interne trigger: stress, overprikkeling, …
-	Action: de tool in fidgetmodus plaatsen, prutsen met fidget
-	Variable reward: positieve invloed van de fidget op je gevoel, je wordt rustiger (zelfregulatie), concentratie in de les, je haalt er plezier uit
-	Investment : … 

Brainstorming investering in de FEELLINK 
- Toe te voegen 
    - personalisatie van de tool
       - kleur
       - soort fidgets
       - een persoonlijk app met feature die aangeeft hoe de leerkracht het kind beter kan begrijpen; geeft aan wat het kind nodig heeft bij welke emotie
       - het overzicht na elke week
    - ze krijgen een soort streak die de leerkracht kan instellen als ze hun emotie positief hebben aangepakt; vragen naar een stiltemoment, spelen met de fidget,…

- Automatisch toegepast
  - tijd; de tijd die het kind met het product doorbrengt
    
  - emotionele investering
  
  Doordat het kind via de tool zijn emoties kan delen en daardoor beter geholpen wordt bij overprikkeling, ontstaat een positief gevoel en een emotionele band met de FEELLINK. Deze emotionele investering motiveert het kind om de tool blijvend te gebruiken. Dit kunnen we achterhalen uit de attachment theory.
  Dit staat verder beschreven in het protocol van deze developfase.

2. NUDGES
   
NUDGES

-	_Motivatie_: vermijden van pijn naar plezier, vermijden van afwijzing en zoeken naar sociale acceptatie
    -	Vermijden van meer pijn ervaren (stress, overprikkeling, stressoren) naar plezier (concentratie, zelfregulatie, beloning na positieve expressie van emotie en goede aanpak…) 
    - Vermijden van afwijzing en zoeken naar sociale acceptatie; als de leerling een bepaalde emotie voelt kan die zoeken naar erkenning van de leerkracht
-	_Ability_: de capaciteiten om de gevoelens te uiten of om de fidget te gebruiken
    -	Fidget gebruiken: 
        - Fysische effort
            - Past de tool makkelijk in een hand? (zie test ergonomie)
            - Zijn de fidgets makkelijk te gebruiken?
        -	Cognitieve load
            - Zijn de kinderen rustig genoeg om de fidget te hanteren?
        -	Routine
        	  - Lijken de fidgets op fidgets die al worden gebruikt, al op de markt bestaan?
    -	Emotie communicatie: 
        - Fysische effort
            - Zijn de knoppen makkelijk indrukbaar? (te grote knoppen, te kleine knoppen?) (ie test ergonomie)
            - Zijn de fidgets makkelijk te gebruiken?
        -	Cognitieve load
            - Zijn de kinderen niet te overstuurd om hun emoties aan te duiden?
            - Is de interface duidelijk en simpel genoeg (Miller’s Law)
        -	Sociale afwijking
        	  - Is het ingeven van de emotie privé genoeg?
             - Wordt de tool door meerdere mensen in de klas gebruikt? (kuddegedrag)

  - _Trigger_ : nudges
    - Brainstorming nudges:
      - Bij lang gebruik van de fidget (meten via timer + bewegingssensor), zal de tool trillen waardoor het kind zich kan herinneren om eens na te denken over hun emotie.
      - Bij het begin van de dag/ na elke pauze is er een visuele nudge / trilling die de kinderen een check in laat doen.
      - Een verandering van kleur van de aan/uit knop.

<ins> PESTEL-analyse </ins>

Er is een analyse ontvangen van studenten uit het vak De kennismaatschappij en ICT. Deze hadden onze Github pagina bekeken en op basis daarvan een PESTEL-analyse uitgevoerd op ons project. Er werden tips en feedback meegedeeld met de kijk vanuit de verschillende aspecten van PESTEL. (Political, Economic, Social, Technological, Environmental en Legal)

<ins> Onderzoeksvraag 2: Hoe kunnen we de user experience nog optimaliseren? </ins>

In het kader van user experience onderzochten we de ideale volgorde van de emotieknoppen op de interface. Dit gebeurde via een codesign test waarbij leerlingen losse knoppen op een bordje konden leggen volgens hun voorkeur. We vroegen daarbij naar hun redenering en observeerden het legproces om inzicht te krijgen in hun keuzes.

Daarnaast testten we de volledige werking van Feellink in een lessimulatie met één werkend prototype. Na elk lessuur gaven we de FEELLINK door tussen leerlingen en deden telkens een kleine aanpassing namens de feedback van het indrukken van knoppen en het versturen van de emoties naar de leerkracht.

set up

De 3 verschillende manieren van feedback:
1.	Als men op een knop drukt zal zijn eigen led branden totdat er op de verzendingsknop wordt gedrukt of totdat ze de knop nog eens indrukken
2.	Als men een knop indrukt zal men een trilling voelen en bij het verzenden van de emoties voelt met een langere trilling
3.	Als men een knop indrukt zal er een ledje flikkeren bij de bevestigingsknop.

Tijdens de test ontvingen wij alle data die de leerling via Feellink doorstuurde. Op basis van die input pasten we in real time de interface van de leerkracht aan via een gedeeld Miro-bord. We zaten beiden achteraan in de klas: één iemand ving de data op, terwijl de andere de interface in het Miro-bord aanpaste. Vooraan in de klas stond een laptop open, zodat de leerkracht de wijzigingen kon volgen. Op die manier werkten we volgens een vorm van Wizard of Oz-testing, waarbij we de indruk wekten dat de interface automatisch functioneerde. Daarnaast gaven we de leerkracht een gsm waarop we de instellingen hadden aangepast. Die ontving enkel trillingsmeldingen wanneer wij handmatig een signaal doorstuurden. Zo testten we het feedbacksysteem met een tijdelijk trillingsdevice.

GITHUB INTERFACE

gihub mkqdfj

VRAGENLIJST TRILLING

1.	Ik vond het makkelijk om de FeelLink te gebruiken.
2.	Ik voelde me op m’n gemak tijdens het gebruik van de FeelLink.
3.	Ik wist wat elke knop betekende. (Zo niet, welke niet?)
4.	Ik vond het duidelijk welke knoppen ik allemaal had ingedrukt.
5.	Ik wist waarom het toestel trilde.
6.	Ik wist wanneer mijn signaal was aangekomen.
7.	Ik vond het duidelijk wanneer ik een emotie had doorgestuurd naar de leerkracht.
8.	Ik merkte een trilling in m’n hand.
9.	Ik vond de trilling aangenaam.
10.	Ik stoorde me aan de trilling aan m’n hand.
11.	Ik durfde meer mijn gevoelens te delen door de FeelLink dan anders.

VRAGENLIJST ALLE LEDS

1.	Ik vond het makkelijk om de FeelLink te gebruiken.
2.	Ik voelde me op m’n gemak tijdens het gebruik van de FeelLink.
3.	Ik wist wat elke knop betekende. (Zo niet, welke niet?)
4.	Ik vond het duidelijk welke knoppen ik allemaal had ingedrukt.
5.	Ik begreep waarom de lichtjes aan en uit gingen.
6.	Ik merkte telkens wanneer een lichtje aanging.
7.	De duur dat het lichtje aanbleef was lang genoeg voor mij.
8.	Zonder het lichtje zou ik niet zeker zijn dat het werkte.
9.	Ik wist wanneer mijn signaal was aangekomen.
10.	Ik vond het duidelijk wanneer ik een emotie had doorgestuurd naar de leerkracht.
11.	Ik durfde meer mijn gevoelens te delen door de FeelLink dan anders.

VRAGENLIJST ENKELE LED

1.	Ik vond het makkelijk om de FeelLink te gebruiken.
2.	Ik voelde me op m’n gemak tijdens het gebruik van de FeelLink.
3.	Ik wist wat elke knop betekende. (Zo niet, welke niet?)
4.	Ik vond het duidelijk welke knoppen ik allemaal had ingedrukt.
5.	Ik begreep waarom het lichtje flikkerde.
6.	Ik merkte telkens wanneer een lichtje aanging.
7.	De duur dat het lichtje aanbleef was lang genoeg voor mij.
8.	Zonder het lichtje zou ik niet zeker zijn dat het werkte.
9.	Ik wist wanneer mijn signaal was aangekomen.
10.	Ik vond het duidelijk wanneer ik een emotie had doorgestuurd naar de leerkracht.
11.	Ik durfde meer mijn gevoelens te delen door de FeelLink dan anders.

VRAGENLIJST LEERKRACHT 

1.	De trilling leidde mij niet af tijdens het lesgeven.
4.	Ik voelde de trilling telkens duidelijk.
5.	De trilling was storend tijdens het lesgeven.
6.	De trilling gaf me een duidelijk signaal dat er een boodschap werd doorgestuurd.
8.	De interface gaf me een duidelijk overzicht van de ontvangen signalen.
9.	De veranderingen in de interface waren visueel duidelijk.
10.	De interface hielp mij om sneller te begrijpen wat het kind bedoelde.
11.	Ik wist goed welke signalen van welke leerlingen kwamen.
12.	De interface leidde niet af van mijn lesactiviteiten.
13.	Door de feedback kon ik sneller inspelen op de noden van de leerling.
14.	Ik voelde mij zekerder in het ondersteunen van de leerling dankzij de FEELLINK-feedback.

bert

### Conclusies & implicaties
We voegen geen extra investment toe, omdat de emotionele band met de Feellink vanzelf ontstaat. Door via de tool gevoelens te uiten en hierbij gepaste steun te ervaren, groeit het vertrouwen en het positieve gevoel rond het gebruik. Volgens de attachment theory zorgt dit voor een duurzame motivatie om de tool te blijven gebruiken, waardoor bijkomende investeringsprikkels niet nodig zijn. Extra investeringen of triggers zouden zelfs contraproductief kunnen zijn, omdat ze het natuurlijke en vrijwillige karakter van de interactie kunnen verstoren.

Na deze brainstorm hadden we al enkele tests uitgevoerd met trilsignalen als vorm van feedback. Hieruit bleek al snel dat dit geen effectieve methode was: de trilling was ofwel te luid en daardoor storend, ofwel te zwak en werd niet opgemerkt bij gebruik. Tijdens de lessimulaties hebben we de Feellink op bepaalde momenten laten trillen wanneer ze langere tijd niet gebruikt werd, maar dit leidde tot geen enkele reactie van de gebruikers. Dit bevestigt dat trilling geen geschikte feedbackvorm is voor deze doelgroep en context.

Verder konden we onze brainstorming niet uitwerken door gebrek aan tijd.

Uit de PESTEL analyse en de argumenten errond werd er besloten de neutrale emotie van de tool te verwijderen. Dit aangezien het een emotie is die niet per se noodzakelijk is om gedeeld te worden en het dus misschien een uitweg kan zijn voor de leerling om zijn echte emotie door te sturen. Daarnaast vonden we nog enkele andere dingen die opgebracht waren interessant om op verder te werken, zoals het draadloos oplaadsysteem achteraan de klas en de economie rond fabricatie en onderhoud. Er werd echter besloten om hier niet dieper op in te gaan en dit buiten de scope van het project te plaatsen omwille van de vrij nabije einddeadline en prioriseringen in testen.

We concluderen dat de emotieknoppen als volgt op de interface zullen staan:
•	Positie 1 : blije emotieknop
•	Positie 2: verdrietige emotieknop
•	Positie 3: verbaasde emotieknop
•	Positie 4: verwarde emotieknop
•	Positie 5: boze emotieknop
Dit is bepaald op basis van waar ze het meest geplaatst zijn, waarbij verdrietig positie 2 opvult.

Uit de tests en de vragenlijsten blijkt dat elke knop best voorzien wordt van LED-verlichting. Zo ziet de leerling meteen of de knop is ingedrukt, wat twijfel voorkomt. Voor het verzenden van emoties wordt een knipperend lampje toegevoegd, omdat dit als de duidelijkste vorm van bevestiging werd ervaren. Ook de trilfunctie voor leerkrachten blijkt essentieel, zodat zij tijdens het rondlopen signalen kunnen blijven ontvangen.
Wat de leerkrachteninterface betreft, werkt de huidige indeling goed om snel te zien welke leerling een emotie verzendt. Wel blijkt een extra aanduiding nodig voor wanneer dezelfde emotie kort na elkaar opnieuw wordt ingedrukt, bijvoorbeeld via een tijdstempel of symbool.

> [!IMPORTANT]
> Design requirements:
> - D2.10: De neutrale emotie mag niet op de tool aanwezig zijn.
> - D2.11: Elke emotieknop moet voorzien zijn van een LED die oplicht bij het indrukken, zodat de gebruiker visueel bevestigd krijgt dat de input geregistreerd is.
> - D2.12: Er moet een knipperend lampje voorzien worden dat aangeeft wanneer een emotie succesvol is verzonden, om zekerheid te bieden aan de gebruiker.
> - D3.11: Het systeem moet een trilfunctie bevatten die meldingen naar een mobiel toestel van de leerkracht stuurt, zodat deze ook tijdens het rondlopen signalen ontvangt.
> - D2.13: De emotieknoppen moeten steeds in dezelfde volgorde geplaatst worden op de interface, namelijk: positie 1 = blij, positie 2 = verdrietig, positie 3 = verbaasd, positie 4 = verward, positie 5 = boos.
> - D1.14: Een nudge mag geen gebruik maken van trillingen.

## Technische beschrijving

<ins> Finale bill of materials </ins>
- thermoplastische rubber (later)
- 3D geprinte casing
- silicone
- ronde drukknoppen
- 7 witte LED's ([Gotron](https://www.gotron.be/componenten/actief/leds/5mm-led/led-5mm-warm-wit-water-clear.html))
- 7 weerstanden
- 1 HC05
- 1 schuifschakelaar
- 1 microcontroller (arduino nano)
- fidgets: draaiend element, textuurmat, joystick, ...
- device met Serial Bluetooth Terminal

<ins> Code </ins>

```cpp

#include<SoftwareSerial.h>

SoftwareSerial B(10, 11);

int ButtonPin7 = 4;

int SwitchPin = A6;
const int Sololampje = 13;

bool knop1 = false;
bool knop2 = false;
bool knop3 = false;
bool knop4 = false;
bool knop5 = false;
bool knop6 = false;

int knopPinnen[] = {2, 3, 8, 5, 6, 7};  // ButtonPin1 t.e.m. ButtonPin6
int ledPinnen[] = {9, 12, A5, A1, A2, A3};
bool* knoppen[] = {&knop1, &knop2, &knop3, &knop4, &knop5, &knop6};

const char* boodschappen[] = {
  "De leerling is verdrietig!",
  "De leerling is boos!",
  "De leerling is blij!",
  "De leerling is verbaasd!",
  "De leerling is verward!",
  "De leerling heeft een vraag!"
};

void setup() {

    B.begin(9600);
    
    for (int i = 0; i < 6; i++) {
        pinMode(knopPinnen[i], INPUT_PULLUP);
        pinMode(ledPinnen[i], OUTPUT);
    }

    pinMode(ButtonPin7, INPUT_PULLUP);

    pinMode(SwitchPin, INPUT);
    pinMode(Sololampje, OUTPUT);

}

void trillertijd(int pin, int duur) {
  digitalWrite(pin, HIGH);
  delay(duur);
  digitalWrite(pin, LOW);
}

void loop() {

//  code die enkel gebeurd als de switch werkt
    if(digitalRead(SwitchPin) == HIGH){

    // wanneer 5 emotieknoppen worden ingeduwd veranderd de staat ervan (toggle aan uit)
        
        for (int i = 0; i < 6; i++) {
            if (digitalRead(knopPinnen[i]) == LOW) {
                *knoppen[i] = !*knoppen[i];
                delay(200);
            }

    // wanneer de knoppen aan getoggled zijn dan moet hun lampje respectievelijk branden
            digitalWrite(ledPinnen[i], *knoppen[i]);
        }

    // wanneer de verzend knop wordt ingeduwd worden de emoties die aan stonden doorgestuurd en worden ze terug afgezet

        if (digitalRead(ButtonPin7) == LOW) { 
            
            trillertijd(Sololampje, 100);
            delay(200);
            trillertijd(Sololampje, 100);

            for (int i = 0; i < 6; i++) {
                if (*knoppen[i] == true) {
                    B.print(boodschappen[i]);
                    B.print(" -----------> Knop ");
                    B.print(i + 1);
                    B.println(" is ingedrukt!");
                    *knoppen[i] = !*knoppen[i];
                }
            }

            B.println("Emoties verzonden!");
            delay(200);
        }
        
    }

    if(digitalRead(SwitchPin) == LOW){
        
        for (int i = 0; i < 6; i++) {
            digitalWrite(ledPinnen[i], LOW);
            *knoppen[i] = false;
        }
    }
 }

```

<ins> Build instructions </ins>

1. Casing

De casing van het product bestaat uit 2 onderdelen, deze kun je over elkaar schuiven om de casing te sluiten. In deze casing zijn er gaten voorzien om de knoppen en LED's door te steken zodat ze kunnen ingedrukt worden. Daarnaast is er op de casing ook plaats voorzien waar dat de fidgets op bevestigd kunnen worden.
De casing zelf zou uit thermoplastische rubber bestaan maar is voorlopig nog ge-3D-print (stl-files te vinden in mapje BillOfMaterials)



2. Elektrische componenten

De elektrische componenten worden aan elkaar geconnecteerd volgens onderstaand elektrisch bedradingsschema. Hierna werden deze ook aan elkaar gesoldeerd en werd er gebruik gemaakt van een custom soldeerbordje gemaakt uit karton zodat de knoppen en LED's op de juiste plek zaten en goed en makkelijk gingen passen in de interface.

BOM_bedradingsschema 1


3. Serial Bluetooth Monitor - applicatie

Dankzij deze applicatie konden we gegevens van de knoppen via de HC-05 Bluetooth-module doorsturen. Zo werd ook de exacte tijd geregistreerd waarop een emotieknop werd ingedrukt.

Daarnaast konden we via de applicatie ook input naar de HC-05 sturen. Dit was bijzonder handig, omdat we de Arduino tijdens de testfase niet telkens uit het prototype hoefden te halen om nieuwe code te uploaden. In plaats daarvan konden we de volledige code vooraf laden en via de applicatie eenvoudig schakelen tussen verschillende codeonderdelen.



4. Silicone

Zowel de fidgets als cover boven de knoppen op het product zijn gemaakt uit silicone. Dit is gebeurd door silicone samen met wat pigment in een mal te gieten. Deze mallen werden ge-3D-print (stl-files te vinden in mapje BillOfMaterials) zodat we de fidgets en knopcovers in exact de juiste maat en vorm konden krijgen.

5. Interfaces leerkrachten

De interfaces voor leerkrachten zijn ontwikkeld op basis van veelgebruikte schoolapplicaties zoals Nearpod, Smartschool en Schoolware. Ze zijn ontworpen in een speelsere en gebruiksvriendelijkere stijl, waarbij ook rekening is gehouden met de ontwerpeisen uit Define Wave 3 en Develop 2. Voor het ontwerp is Affinity Designer gebruikt. Alle ontworpen interfaces zijn te zien in het mapje interfaces leerkrachten.

## Kritische reflectie

<ins> SEMESTER 1 </ins>

Tijdens ons lopende project hebben we ervaren hoe essentieel het is om een grondige voorkennis en diepgaand inzicht te hebben in ASS (autismespectrumstoornis) om een product te ontwerpen dat aansluit bij de specifieke noden van deze doelgroep. De complexiteit van ASS als spectrumstoornis maakt het echter uitdagend om een universele oplossing te bieden. Elk individu met ASS is uniek, en waar sommige kinderen moeite hebben met het uiten van hun gevoelens, ervaren anderen die drempel veel minder. Dit werd duidelijk tijdens onze gebruikerstests, waarin de diversiteit van ervaringen en behoeften naar voren kwam. 

Een belangrijk aspect van ons product is de ontwikkeling van een ondersteunende app. Om de interface-indeling te testen, hebben we in onze derde wave gekozen voor een enquête, aangezien deze fase zich dicht bij de kerstvakantie bevond. Met een enquête konden we efficiënt en snel feedback verzamelen zonder fysieke afspraken te maken met leerkrachten, wat moeilijk te organiseren was in deze periode. Helaas bleef de respons onder onze verwachtingen, waardoor we nog wachten met het opstellen van een volledig verslag. Dit gebrek aan data is jammer, omdat het ons verhindert om conclusies te trekken en verdere stappen te nemen. 

Daarnaast hebben we nog meer gebruikerstests nodig om ons product goed in context te plaatsen. We willen aspecten zoals de bevestiging op de schoolbanken, het oplaadsysteem en de plaatsing van de knoppen verder optimaliseren. Door deze praktische toepassingen te testen, kunnen we zorgen voor een naadloze integratie in de klasomgeving en een betere gebruikerservaring. Een groot voordeel van samenwerken met scholen is dat zij een breed testpubliek bieden. De scholen waarmee we werken, zijn enthousiast over ons project en ondersteunen graag de verdere ontwikkeling. Hun positieve houding en bereidheid tot samenwerking motiveren ons enorm, en het is bemoedigend om te zien hoe zij onze inzet voor kinderen met ASS waarderen. 

Voor de projectplanning hebben we gebruik gemaakt van Trello, wat ons hielp om het overzicht te bewaren. Toch liep de planning niet altijd even soepel. Onze eerste wave kon pas laat plaatsvinden door beperkte beschikbaarheid van de school die eerder bezocht waren door Aster. Hoewel de school uiteindelijk akkoord ging, mocht Aimé niet deelnemen aan deze wave aangezien Aster op die school al een interview en observatiedag had gehad en het moeizamer zou zijn voor de kinderen om hun emoties te delen met een onbekende en onvertrouwde persoon erbij. Dit was een teleurstelling, omdat we de inzichten van beide teamleden hadden willen combineren voor een completere evaluatie. Met twee personen was het bovendien makkelijker geweest om de kinderen snel te testen, aangezien we onder tijdsdruk stonden door het lesrooster. 

De samenwerking binnen ons team verliep echter vlot. De taken waren goed verdeeld, en een belangrijk pluspunt was dat Aimé voor de pitch ook al bezig was met onderzoek rond kinderen met ASS. Hierdoor konden onze bevindingen gebundeld worden en verschillende perspectieven samenbracht worden. Bovendien is dit project voor ons beiden persoonlijk, aangezien we allebei een broer met autisme hebben. Dit persoonlijke verband heeft ons extra gemotiveerd om een betekenisvolle bijdrage te leveren.

<ins> SEMESTER 2 </ins>

Na het tweede semester kijken we met voldoening terug op wat we tot nu toe gerealiseerd hebben. We zijn trots op de stappen die we hebben gezet, maar beseffen tegelijk dat het project nog niet af is. Er blijven nog belangrijke elementen over die verder uitgewerkt en getest moeten worden. Zo willen we de nudges beter onderbouwen met uitgebreidere testen, extra iteraties van de interface uitvoeren, een trilfeedbacksysteem ontwikkelen dat specifiek gericht is op leerkrachten en ook een draadloos oplaadsysteem ontwerpen. Helaas was hier binnen de beschikbare tijd geen ruimte meer voor.

Een van de grootste struikelblokken ontstond na de eerste ontwikkelingsfase (develop 1). Waar we in het begin vlot contact hadden met scholen, viel dat contact plots stil. We kregen geen reacties meer, wat een duidelijke blokkage veroorzaakte in onze testplanning. In develop 2 hadden we een onderzoeksvraag met meer focus op de leerkrachten. Achteraf gezien was dit misschien te veel gevraagd. Leerkrachten hebben het al druk, en de bereidheid om diepgaand deel te nemen bleek beperkt. Dit hadden we ook al ondervonden tijdens define wave 3, toen we een enquête uitstuurden en daar nauwelijks respons op kregen. Aanvankelijk dachten we dat dit lag aan de vorm van de enquête en de periode van het jaar (vakantieperiode), maar uiteindelijk werd duidelijk dat de beperkte betrokkenheid eerder te maken had met een overvraging van de doelgroep.

We zijn ons er ook van bewust dat we sommige testen anders konden aanpakken. Zo was het ideaal geweest om in de lessimulatie met meerdere FEELLINKS te werken, of om vroeger in het proces de indrukbare knopjes grondiger te testen. Helaas beschikten we niet over voldoende Arduino’s of HC-05 modules om deze tests uit te voeren met Bluetooth-functionaliteit. Bovendien moesten de knopjes stevig bevestigd worden in de prototypes, wat het lastig maakte om ze netjes te hergebruiken of snel te wisselen voor een ander ontwerp. Deze praktische beperkingen hebben onze testmogelijkheden dus sterk beïnvloed.

Ondanks deze uitdagingen kunnen we terugkijken op een vlotte en positieve samenwerking binnen het team. Net als in het eerste semester gebruikten we Trello om onze taken te plannen, wat hielp om structuur te behouden. De gedeelde mappen maakten het makkelijk om elkaars werk op te volgen en aan te vullen waar nodig. We hebben goed op elkaar ingespeeld.

Wat ons sterk bijbleef is het enthousiasme van zowel leerlingen als leerkrachten tijdens de testen, vooral tijdens de lessimulatie. Velen gingen ervan uit dat FEELLINK een echt product zou worden en vonden het jammer dat het project zou stoppen. Dit geeft aan dat ons werk er wel toe doet. 

Ook wij vinden het jammer dat het project hier eindigt zonder volledige uitwerking. Toch nemen we er veel inzichten en motivatie uit mee naar volgende projecten.

## Design Requirements

| Nummer  | Design requirement | Source | Datum |
| --- | --- | --- | --- |
| **D1**  | **Algemene eisen** |  |  |
| D1.1 | Het product moet stevig zijn zodat leerlingen het niet makkelijk uit elkaar kunnen halen. | Discovery | 30/10/2024 |
| D1.2 | Het gebruiksdoel moet duidelijk aangegeven zijn. | Discovery | 30/10/2024 |
| D1.3 | Er moet ruimte zijn voor fouten. | Discovery | 30/10/2024 |
| D1.4 | Het product mag heel weinig tot liefst geen geluid maken. | Discovery | 30/10/2024 |
| D1.5 | Het product moet kubusvormig zijn en moet een neutrale kleur hebben om goed in het klasbeeld te blenderen. | Discovery ‘A day in the life’ | 21/10/2024 |
| D1.6 | Er moet een draaiend fidgeting element aanwezig zijn. | Definition wave 1 | 06/12/2024 |
| D1.7 | Het de buitenkant van het product moet gemaakt zijn van thermoplastische rubber. | Definition wave 2 | 13/12/2024 |
| D1.8 | Er moet een element zijn op het product met dezelfde kenmerken in indrukbaarheid als de ‘middelste textuurmat’ van het touch and feel board. | Definition wave 2 | 13/12/2024 |
| D1.9 | De plaats van de tool in de klas is op de persoonlijke bank van de leerlingen. | Develop 1 | 12/3/2025 |
| D1.10 | De fysieke interface moet lichtjes bevatten die aantonen dat de knoppen aanstaan en werken. | Develop 1 | 12/3/2025 |
| D1.11 | De leerlingen moeten in de fidget kunnen knijpen zonder zichzelf pijn te doen en zonder de tool kapot te maken. | Develop 1 | 12/3/2025 |
| D1.12 | De aan/uit knop is een switchknop die groter is dan 9x4 mm. | Develop 2 | 14/5/2025 |
| D1.13 | De feedback op het aan- /uitzetten van de FEELLINK moet visueel maar subtiel zijn (=een verlichte bevestigingsknop + aanduiding bij de knop) | Develop 2 | 14/5/2025 |
| D1.14 | Een nudge mag geen gebruik maken van trillingen. | Develop 3 | 19/5/2025 |
| **D2**  | **Emoties aanduiden** |  |  |
| D2.1 | Bij het aanduiden van emoties moeten kleuren gebruikt worden. | Discovery benchmarking | 28/10/2024 |
| D2.2 | Het aanduiden van emoties moet onopvallend kunnen gebeuren ten opzichte van de medeleerlingen. | Discovery benchmarking | 28/10/2024 |
| D2.3 | Bij het aanduiden van emoties moeten gezichtsuitdrukkingen gebruikt worden. | Discovery | 30/10/2024 |
| D2.4 | Je moet meerdere verschillende emoties tegelijk kunnen aanduiden. | Definition wave 2 | 13/12/2024 |
| D2.5 | De emoties moeten zo simpel mogelijk gehouden worden. | Definition wave 2 | 13/12/2024 |
| D2.6 | De emoties moeten aangeduid kunnen worden aan de hand van verschillende knoppen. | Definition wave 2 | 13/12/2024 |
| D2.7 | Er moet een bevestigingsknop zijn om de error proofness te vergroten. | Definition wave 2 | 13/12/2024 |
| D2.8 | Er moet een knop aanwezig met een vraagteken dat betekent dat er een vraag is en er een leerkracht moet komen. | Definition wave 2 | 13/12/2024 |
| D2.9 | De emotie-kleur verdeling moet zijn: verdriet = blauw, blij = geel, boos = rood, verbaasd = roze, neutraal = oranje , verward = bruin. | Definition wave 2 | 13/12/2024 |
| D2.10 |De neutrale emotie mag niet op de tool aanwezig zijn. | Develop 3, PESTEL-analyse | 24/4/2025 |
| D2.11 | Elke emotieknop moet voorzien zijn van een LED die oplicht bij het indrukken, zodat de gebruiker visueel bevestigd krijgt dat de input geregistreerd is. | Develop 3, lessimulatie | 19/5/2025 |
| D2.12 | Er moet een knipperend lampje voorzien worden dat aangeeft wanneer een emotie succesvol is verzonden, om zekerheid te bieden aan de gebruiker. | Develop 3, lessimulatie | 19/5/2025 |
| D2.13 | De emotieknoppen moeten steeds in dezelfde volgorde geplaatst worden op de interface, namelijk: positie 1 = blij, positie 2 = verdrietig, positie 3 = verbaasd, positie 4 = verward, positie 5 = boos. | Develop 3 | 14/5/2025 |
| **D3** | **Leerkracht** |  |  |
| D3.1 | De app mag niet zichtbaar op de laptop zijn wanneer verbonden met digibord/beamer. | Discovery ‘A day in the life’ | 21/10/2024 |
| D3.2 | We moeten werken met dezelfde kleuren + emojis als van de FEELLINK. | Develop 2 | 5/5/2025 |
| D3.3 | De leerkrachten krijgen in real-time de meldingen binnen. | Develop 2 | 5/5/2025  |
| D3.4 | Het moet een mogelijkheid zijn om een gast toe te kunnen voegen bij het co-teachen of als er hulp moet ingeschakeld worden. | Develop 2 | 5/5/2025  |
| D3.5 | Bij de emotie blij hoeft er geen melding gegeven worden. | Develop 2 | 5/5/2025  |
| D3.6 | De interface mag niet gekoppeld worden aan de gsm (privé niet koppelen aan werk). | Develop 2 | 5/5/2025  |
| D3.7 | Een stille trilling is een ideale manier van een melding ontvangen. | Develop 2 | 5/5/2025  |
| D3.8 | Het bijhouden van de data in een weekoverzicht per leerling is handig voor de klassenraden. | Develop 2 | 5/5/2025  |
| D3.9 | Er moet een optie zijn om de meldingen voor een bepaalde periode te snoozen (na de bepaalde periode zullen de meldingen automatisch ingeschakeld zijn) | Develop 2 | 5/5/2025  |
| D3.10 | De leerkracht krijgt enkel meldingen als die lesgeeft aan de klas. | Develop 2 | 5/5/2025  |
| D3.11 | Het systeem moet een trilfunctie bevatten die meldingen naar een mobiel toestel van de leerkracht stuurt, zodat deze ook tijdens het rondlopen signalen ontvangt. | Develop 3, lessimulatie | 19/5/2025  |
| **D4** | **Ergonomie** |  |  |
| D4.1 | De grootte van de tool (kubus) is 79 cm. | Develop 1 | 12/3/2025 |
| D4.2 | De knoppen op de fysieke interface moeten een diameter hebben van 20 mm. | Develop 1 | 12/3/2025 |
| D4.3 | De knoppen op de fysieke interface moeten allemaal dezelfde grootte hebben. | Develop 1 | 12/3/2025 |
| D4.4 | De knoppen op de fysieke interface moeten voldoen ver van elkaar gespreid zijn en dus niet vlak naast elkaar staan. | Develop 1 | 12/3/2025 |
| D4.5 | De door de leerlingen het meest gebruikte knoppen moeten het makkelijkst bereikbaar zijn binnen de range of motion van de duimen. | Develop 1 | 12/3/2025 |
| D4.6 | Het maximaal gewicht van de tool is 200g | Develop 2 | 26/4/2025 |

## Bijlagen

**Discovery**
-	Protocol
    - [Interview](https://ugentbe-my.sharepoint.com/:w:/g/personal/aster_vuylsteke_ugent_be/ERDiAZO5nPxBjzCxDWfCPgABJusLvoNUR7Z7kE3nOPYccg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)
    - [Literatuuronderzoek](https://ugentbe-my.sharepoint.com/:w:/g/personal/aster_vuylsteke_ugent_be/EfF0zFRiwRNHqrxJJkOKhiQBagrojCyjMdQhFmKGb2fW6Q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)
    - [Benchmarking](https://ugentbe-my.sharepoint.com/:w:/g/personal/aster_vuylsteke_ugent_be/ESQnX2wANUtFrpu7xw_naMIBqzeu5zEyD0b7LqGH7DogWw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)
    - [Expertinterview](https://ugentbe-my.sharepoint.com/:w:/g/personal/aster_vuylsteke_ugent_be/EcCIeTubRUtGtPKPhhBLgdMBBp3u9nu4HagC_Zvy1GGE9w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)
-	Report 
    - [Interview, day in the life](https://ugentbe-my.sharepoint.com/:w:/g/personal/aster_vuylsteke_ugent_be/EbXXsjpG5ydBoG-LV-Z2z7UBRn0qrCNRL4vNs0sjmX7OHA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)
    - [Literatuuronderzoek](https://ugentbe-my.sharepoint.com/:w:/g/personal/aster_vuylsteke_ugent_be/ETPTrznzu9hBhJNWGq1PPxUBbNnAE-lKLgXP25Z5kOwpXw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)
    - [Benchmarking](https://ugentbe-my.sharepoint.com/:w:/g/personal/aster_vuylsteke_ugent_be/EbA8KuhzujxHg4QFj2ktJZ8BLwU4Pm_4NY6t16D52hl6nQ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)
    - [Expertinterview](https://ugentbe-my.sharepoint.com/:w:/g/personal/aster_vuylsteke_ugent_be/EYsLfmsywaFLqIKh9--rWfQBYwKdGqoVnoFl01wBaEcTjg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)

**Definition**
-	Protocol
    - [Wave 1](https://ugentbe-my.sharepoint.com/:w:/g/personal/aster_vuylsteke_ugent_be/EQzFRJSVKgVHvhpB29MW8mwBDQ7O6rRJMIT918KuWzWjxw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)
    - [Wave 2](https://ugentbe-my.sharepoint.com/:w:/g/personal/aster_vuylsteke_ugent_be/EcqheMuVSRhEkQV2BDz-iyMB4MqHqlQu4m8pRMHQAFeDyg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)
    - [Wave 3](https://ugentbe-my.sharepoint.com/:w:/g/personal/aster_vuylsteke_ugent_be/EYNmwyldCFJKidc277lI98UB3p2W4cRhaNx9lIBYMmKWng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)
-	Report
    - [Wave 1](https://ugentbe-my.sharepoint.com/:w:/g/personal/aster_vuylsteke_ugent_be/EbCdK86V4D5EqtiuHMK7OPQBUEJYx8QuLB-m6AszW0D-Ug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)
    - [Wave 2](https://ugentbe-my.sharepoint.com/:w:/g/personal/aster_vuylsteke_ugent_be/EST_ebFZIlpGhgP4mV9fN6AB26-MVDRm-yiT8R5wLcJ2rw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)
    - [Wave 3](https://ugentbe-my.sharepoint.com/:w:/g/personal/aster_vuylsteke_ugent_be/ETFXeHp6ypxMi6rCLQbqeeABHassiN-m-b7oYoHdmw8uig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)

**Develop**
- protocol
  - [Develop wave 1](https://ugentbe-my.sharepoint.com/:w:/g/personal/aster_vuylsteke_ugent_be/EcwJWgr-xsBJjngo-9FJzZwBsNQBkmoPG4wla99mNBSVtA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)
  - [Develop wave 2](https://ugentbe-my.sharepoint.com/:w:/g/personal/aster_vuylsteke_ugent_be/EejmUnNeMNFEjsj-9BCKlJkBLbdw6e6AeDup7qnyZyZ91Q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)
  - [Develop wave 3](https://ugentbe-my.sharepoint.com/:w:/g/personal/aster_vuylsteke_ugent_be/EcYTZnFerQpDj0eg7eIXzvoB0uRsl7Z3En2yfOHTXnrhGA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)
- report
  - [Develop wave 1](https://ugentbe-my.sharepoint.com/:w:/g/personal/aster_vuylsteke_ugent_be/EV3ZKc4KRPtKllTtCGGaY94BTPROrd_bZDGaFCj3kz3DkQ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)
  - [Develop wave 2](https://ugentbe-my.sharepoint.com/:w:/g/personal/aster_vuylsteke_ugent_be/EbNVyaqHaJtMg0e7sJLOAjsBvLlpE9gyNBSCZp0jFgEYDQ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)
  - [Develop wave 3](https://ugentbe-my.sharepoint.com/:w:/g/personal/aster_vuylsteke_ugent_be/EQIKyDxqgS5HkR-E2PZK00UBrE9afi9QE5m03gJtK3fpnQ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)

- Pestel-analyse
  - [Report PESTEL-analyse](https://ugentbe-my.sharepoint.com/:w:/g/personal/aster_vuylsteke_ugent_be/Edba3LgmJX9BgD9vSkCcdPABsAu8UNJzoBpfg0GzRIj6jw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)

**Storyboard**

storyboard
storyboard leerkracht

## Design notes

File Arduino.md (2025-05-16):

# Feellink code

## Opdracht

De FEELLINK stelt de leerling uit het type 9 onderwijs in staat om zijn emoties te delen met de leerkracht. 

Dit gebeurd aan de hand van een aantal knoppen, 6 statusknoppen en emotie verstuurknop.

Elke statusknop bevat een LED, die aan toggled indien de knop wordt ingedrukt. Daarnaast zal er ook een klein trilsignaal gegeven worden als een statusknop wordt ingedrukt. 

Als de verstuurknop wordt ingedrukt dan worden alle emoties die op dat moment aan staan doorgestuurd naar de leerkracht via bleutooth aan de hand van een hc05. Hierbij is er ook een trilling die iets langer is als de statusknoptrilling. De emotiestatussen zullen gereset worden en terug allemaal uit staan.

## bedradingsschema
versie finaal schema

## code finaal opkomende technologieën

```cpp

#include<SoftwareSerial.h>

SoftwareSerial B(10, 11);

int ButtonPin7 = 4;

int SwitchPin = A6;
const int Triller = A4;
const int Sololampje = 13;

bool knop1 = false;
bool knop2 = false;
bool knop3 = false;
bool knop4 = false;
bool knop5 = false;
bool knop6 = false;

int knopPinnen[] = {2, 3, 8, 5, 6, 7};  // ButtonPin1 t.e.m. ButtonPin6
int ledPinnen[] = {9, 12, A5, A1, A2, A3};
bool* knoppen[] = {&knop1, &knop2, &knop3, &knop4, &knop5, &knop6};

const char* boodschappen[] = {
  "De leerling is verdrietig!",
  "De leerling is boos!",
  "De leerling is blij!",
  "De leerling is verbaasd!",
  "De leerling is verward!",
  "De leerling heeft een vraag!"
};

void setup() {

    B.begin(9600);
    
    for (int i = 0; i < 6; i++) {
        pinMode(knopPinnen[i], INPUT_PULLUP);
        pinMode(ledPinnen[i], OUTPUT);
    }

    pinMode(ButtonPin7, INPUT_PULLUP);

    pinMode(SwitchPin, INPUT);
    pinMode(Triller, OUTPUT);
    pinMode(Sololampje, OUTPUT);

}

void trillertijd(int pin, int duur) {
  digitalWrite(pin, HIGH);
  delay(duur);
  digitalWrite(pin, LOW);
}

void loop() {

//  code die enkel gebeurd als de switch werkt
    //if(digitalRead(SwitchPin) == HIGH){

    // wanneer 5 emotieknoppen worden ingeduwd veranderd de staat ervan (toggle aan uit)
        
        for (int i = 0; i < 6; i++) {
            if (digitalRead(knopPinnen[i]) == LOW) {
                *knoppen[i] = !*knoppen[i];
                trillertijd(Triller, 200);
                //trillertijd(Sololampje, 200);
                delay(200);
            }

    // wanneer de knoppen aan getoggled zijn dan moet hun lampje respectievelijk branden
            digitalWrite(ledPinnen[i], *knoppen[i]);
        }

    // wanneer de verzend knop wordt ingeduwd worden de emoties die aan stonden doorgestuurd en worden ze terug afgezet

        if (digitalRead(ButtonPin7) == LOW) { 
            trillertijd(Triller, 500);
            
            //trillertijd(Sololampje, 100);
            //trillertijd(Sololampje, 100);

            for (int i = 0; i < 6; i++) {
                if (*knoppen[i] == true) {
                    B.print(boodschappen[i]);
                    B.print(" -----------> Knop ");
                    B.print(i + 1);
                    B.println(" is ingedrukt!");
                    *knoppen[i] = !*knoppen[i];
                }
            }

            B.println("Emoties verzonden!");
            delay(200);
        }
        
    }

```

## code alles tesamen

```cpp

#include<SoftwareSerial.h>

SoftwareSerial B(10, 11);

int ButtonPin1= 2;
int ButtonPin2= 3;
int ButtonPin3= 8;
int ButtonPin4= 5;
int ButtonPin5= 6;
int ButtonPin6= 7;
int ButtonPin7 = 4;

int LedPin1 = 9;
int LedPin2 = 12;
int LedPin3 = A5;
int LedPin4 = A1;
int LedPin5 = A2;
int LedPin6 = A3;

int SwitchPint = A6;
const int Triller = A4;
const int Sololampje = 13;

bool knop1 = false;
bool knop2 = false;
bool knop3 = false;
bool knop4 = false;
bool knop5 = false;
bool knop6 = false;

void setup() {

    B.begin(9600);
    pinMode(ButtonPin1, INPUT_PULLUP);
    pinMode(ButtonPin2, INPUT_PULLUP);
    pinMode(ButtonPin3, INPUT_PULLUP);
    pinMode(ButtonPin4, INPUT_PULLUP);
    pinMode(ButtonPin5, INPUT_PULLUP);
    pinMode(ButtonPin6, INPUT_PULLUP);
    pinMode(ButtonPin7, INPUT_PULLUP);

    pinMode(SwitchPin, INPUT);
    pinMode(Triller, OUTPUT);
    pinMode(Sololampje, OUTPUT);

    pinMode(LedPin1, OUTPUT);
    pinMode(LedPin2, OUTPUT);
    pinMode(LedPin3, OUTPUT);
    pinMode(LedPin4, OUTPUT);
    pinMode(LedPin5, OUTPUT);
    pinMode(LedPin6, OUTPUT);

}

void trillertijd(int pin, int duur) {
  digitalWrite(pin, HIGH);
  delay(duur);
  digitalWrite(pin, LOW);
}

void loop() {

//  code die enkel gebeurd als de switch werkt
    if(digitalRead(SwitchPin) == HIGH){

    // wanneer 5 emotieknoppen worden ingeduwd veranderd de staat ervan (toggle aan uit)
        if (digitalRead(ButtonPin1) == LOW) {  
            knop1 = !knop1; 
            trillertijd(Triller, 200);
            //trillertijd(Sololampje, 200);
            delay(200);
        } 

        if (digitalRead(ButtonPin2) == LOW) {  
            knop2 = !knop2;
            trillertijd(Triller, 200);
            //trillertijd(Sololampje, 200);
            delay(200);
        } 

        if (digitalRead(ButtonPin3) == LOW) {  
            knop3 = !knop3;
            trillertijd(Triller, 200);
            //trillertijd(Sololampje, 200);
            delay(200);
        } 
        
        if (digitalRead(ButtonPin4) == LOW) {  
            knop4 = !knop4;
            trillertijd(Triller, 200);
            //trillertijd(Sololampje, 200);
            delay(200);
        }    

        if (digitalRead(ButtonPin5) == LOW) {  
            knop5 = !knop5;
            trillertijd(Triller, 200);
            //trillertijd(Sololampje, 200);
            delay(200);
        }

        if (digitalRead(ButtonPin6) == LOW) {  
            knop6 = !knop6;
            trillertijd(Triller, 200);
            //trillertijd(Sololampje, 200);
            
            delay(200);
        }

    // wanneer de knoppen aan getoggled zijn dan moet hun lampje respectievelijk branden
        digitalWrite(LedPin1, knop1);
        digitalWrite(LedPin2, knop2);
        digitalWrite(LedPin3, knop3);
        digitalWrite(LedPin4, knop4);
        digitalWrite(LedPin5, knop5);
        digitalWrite(LedPin6, knop6);

    // wanneer de verzend knop wordt ingeduwd worden de emoties die aan stonden doorgestuurd en worden ze terug afgezet

        if (digitalRead(ButtonPin7) == LOW) { 
            trillertijd(Triller, 500);
            
            //trillertijd(Sololampje, 100);
            //trillertijd(Sololampje, 100);

            if (knop1 == true){
                B.println("De leerling is verdrietig! -----------> Knop 1 is ingedrukt!");
                knop1 = !knop1;
            }
            if (knop2 == true){
                B.println("De leerling is boos! -----------> Knop 2 is ingedrukt!");
                knop2 = !knop2;
            }
            if (knop3 == true){
                B.println("De leerling is blij! -----------> Knop 3 is ingedrukt!");
                knop3 = !knop3;
            }
            if (knop4 == true){
                B.println("De leerling is verbaasd! -----------> Knop 4 is ingedrukt!");
                knop4 = !knop4;
            }
            if (knop5 == true){
                B.println("De leerling is verward! -----------> Knop 5 is ingedrukt!");
                knop5 = !knop5;

            }

            if (knop6 == true){
                B.println("De leerling heeft een vraag! -----------> Knop 6 is ingedrukt!");
                knop6 = !knop6;

            }

            B.println("Emoties verzonden!");
            delay(200);
        }
        
    }

     if(digitalRead(SwitchPin) == LOW){
         digitalWrite(LedPin1, LOW);
         digitalWrite(LedPin2, LOW);
         digitalWrite(LedPin3, LOW);
         digitalWrite(LedPin4, LOW);
         digitalWrite(LedPin5, LOW);
         digitalWrite(LedPin5, LOW);
        
         knop1 = false;
         knop2 = false;
         knop3 = false;
         knop4 = false;
         knop5 = false;
         knop6 = false;

     }
 }
```
## code geen feedback

```cpp

#include<SoftwareSerial.h>

SoftwareSerial B(10, 11);

int ButtonPin1= 2;
int ButtonPin2= 3;
int ButtonPin3= 4;
int ButtonPin4= 5;
int ButtonPin5= 6;
int ButtonPin6= 7;

int SwitchPin = A3;

bool knop1 = false;
bool knop2 = false;
bool knop3 = false;
bool knop4 = false;
bool knop5 = false;

void setup() {

    B.begin(9600);
    pinMode(ButtonPin1, INPUT_PULLUP);
    pinMode(ButtonPin2, INPUT_PULLUP);
    pinMode(ButtonPin3, INPUT_PULLUP);
    pinMode(ButtonPin4, INPUT_PULLUP);
    pinMode(ButtonPin5, INPUT_PULLUP);
    pinMode(ButtonPin6, INPUT_PULLUP);

    pinMode(SwitchPin, INPUT);

}

void loop() {

//  code die enkel gebeurd als de switch werkt
    if(digitalRead(SwitchPin) == HIGH){

    // wanneer 5 emotieknoppen worden ingeduwd veranderd de staat ervan (toggle aan uit)
        if (digitalRead(ButtonPin1) == LOW) {  
            knop1 = !knop1; 
            delay(200);
        } 

        if (digitalRead(ButtonPin2) == LOW) {  
            knop2 = !knop2;
            delay(200);
        } 

        if (digitalRead(ButtonPin3) == LOW) {  
            knop3 = !knop3;
            delay(200);
        } 
        
        if (digitalRead(ButtonPin4) == LOW) {  
            knop4 = !knop4;
            delay(200);
        }    

        if (digitalRead(ButtonPin5) == LOW) {  
            knop5 = !knop5;
            delay(200);
        }

    // wanneer de verzend knop wordt ingeduwd worden de emoties die aan stonden doorgestuurd en worden ze terug afgezet

        if (digitalRead(ButtonPin6) == LOW) { 

            if (knop1 == true){
                B.println("Knop 1 is ingedrukt!");
                knop1 = !knop1;
            }
            if (knop2 == true){
                B.println("Knop 2 is ingedrukt!");
                knop2 = !knop2;
            }
            if (knop3 == true){
                B.println("Knop 3 is ingedrukt!");
                knop3 = !knop3;
            }
            if (knop4 == true){
                B.println("Knop 4 is ingedrukt!");
                knop4 = !knop4;
            }
            if (knop5 == true){
                B.println("Knop 5 is ingedrukt!");
                knop5 = !knop5;

            }
            
            B.println("Emoties verzonden!");
            delay(200);
        }
        
    }

    if(digitalRead(SwitchPin) == LOW){
        
        knop1 = false;
        knop2 = false;
        knop3 = false;
        knop4 = false;
        knop5 = false;

    }
}

```

## code Sololedje + triller

```cpp

#include<SoftwareSerial.h>

SoftwareSerial B(10, 11);

int ButtonPin1= 2;
int ButtonPin2= 3;
int ButtonPin3= 4;
int ButtonPin4= 5;
int ButtonPin5= 6;
int ButtonPin6= 7;

int SwitchPin = A3;

const int Triller = A4;
const int Sololampje = A5;

bool knop1 = false;
bool knop2 = false;
bool knop3 = false;
bool knop4 = false;
bool knop5 = false;

void setup() {

    B.begin(9600);
    pinMode(ButtonPin1, INPUT_PULLUP);
    pinMode(ButtonPin2, INPUT_PULLUP);
    pinMode(ButtonPin3, INPUT_PULLUP);
    pinMode(ButtonPin4, INPUT_PULLUP);
    pinMode(ButtonPin5, INPUT_PULLUP);
    pinMode(ButtonPin6, INPUT_PULLUP);

    pinMode(SwitchPin, INPUT);

    pinMode(Triller, OUTPUT);
    pinMode(Sololampje, OUTPUT);

}

void trillertijd(int pin, int duur) {
  digitalWrite(pin, HIGH);
  delay(duur);
  digitalWrite(pin, LOW);
}

void loop() {

//  code die enkel gebeurd als de switch werkt
    if(digitalRead(SwitchPin) == HIGH){

    // wanneer 5 emotieknoppen worden ingeduwd veranderd de staat ervan (toggle aan uit)
        if (digitalRead(ButtonPin1) == LOW) {  
            knop1 = !knop1; 
            trillertijd(Triller, 200);
            trillertijd(Sololampje, 200);

            delay(200);
        } 

        if (digitalRead(ButtonPin2) == LOW) {  
            knop2 = !knop2;
            trillertijd(Triller, 200);
            trillertijd(Sololampje, 200);
            delay(200);
        } 

        if (digitalRead(ButtonPin3) == LOW) {  
            knop3 = !knop3;
            trillertijd(Triller, 200);
            trillertijd(Sololampje, 200);
            delay(200);
        } 
        
        if (digitalRead(ButtonPin4) == LOW) {  
            knop4 = !knop4;
            trillertijd(Triller, 200);
            trillertijd(Sololampje, 200);
            delay(200);
        }    

        if (digitalRead(ButtonPin5) == LOW) {  
            knop5 = !knop5;
            trillertijd(Triller, 200);
            trillertijd(Sololampje, 200);
            delay(200);
        }

    // wanneer de verzend knop wordt ingeduwd worden de emoties die aan stonden doorgestuurd en worden ze terug afgezet

        if (digitalRead(ButtonPin6) == LOW) { 
            
            digitalWrite(Triller, HIGH);
            digitalWrite(Sololampje, HIGH);

            delay(100);

            digitalWrite(Sololampje, LOW);

            delay(100);
            
            digitalWrite(Sololampje, HIGH);
            delay(100);
            digitalWrite(Sololampje, LOW);

            delay(200);
            digitalWrite(Triller, LOW);

            if (knop1 == true){
                B.println("Knop 1 is ingedrukt!");
                knop1 = !knop1;
            }
            if (knop2 == true){
                B.println("Knop 2 is ingedrukt!");
                knop2 = !knop2;
            }
            if (knop3 == true){
                B.println("Knop 3 is ingedrukt!");
                knop3 = !knop3;
            }
            if (knop4 == true){
                B.println("Knop 4 is ingedrukt!");
                knop4 = !knop4;
            }
            if (knop5 == true){
                B.println("Knop 5 is ingedrukt!");
                knop5 = !knop5;

            }
            
            B.println("Emoties verzonden!");
            delay(200);
        }
        
    }

    if(digitalRead(SwitchPin) == LOW){
        
        knop1 = false;
        knop2 = false;
        knop3 = false;
        knop4 = false;
        knop5 = false;

    }
}

```

## code alle ledjes per emotieknop + triller
```cpp

#include<SoftwareSerial.h>

SoftwareSerial B(10, 11);

int ButtonPin1= 2;
int ButtonPin2= 3;
int ButtonPin3= 4;
int ButtonPin4= 5;
int ButtonPin5= 6;
int ButtonPin6= 7;

int LedPin1 = A1;
int LedPin2 = 8;
int LedPin3 = 9;
int LedPin4 = 12;
int LedPin5 = 13;

int SwitchPin = A3;

const int Triller = A4;

bool knop1 = false;
bool knop2 = false;
bool knop3 = false;
bool knop4 = false;
bool knop5 = false;

void setup() {

    B.begin(9600);
    pinMode(ButtonPin1, INPUT_PULLUP);
    pinMode(ButtonPin2, INPUT_PULLUP);
    pinMode(ButtonPin3, INPUT_PULLUP);
    pinMode(ButtonPin4, INPUT_PULLUP);
    pinMode(ButtonPin5, INPUT_PULLUP);
    pinMode(ButtonPin6, INPUT_PULLUP);

    pinMode(SwitchPin, INPUT);

    pinMode(Triller, OUTPUT);

    pinMode(LedPin1, OUTPUT);
    pinMode(LedPin2, OUTPUT);
    pinMode(LedPin3, OUTPUT);
    pinMode(LedPin4, OUTPUT);
    pinMode(LedPin5, OUTPUT);
}

void trillertijd(int pin, int duur) {
  digitalWrite(pin, HIGH);
  delay(duur);
  digitalWrite(pin, LOW);
}

void loop() {

//  code die enkel gebeurd als de switch werkt
    if(digitalRead(SwitchPin) == HIGH){

    // wanneer 5 emotieknoppen worden ingeduwd veranderd de staat ervan (toggle aan uit)
        if (digitalRead(ButtonPin1) == LOW) {  
            knop1 = !knop1; 
            trillertijd(Triller, 200);
            delay(200);
        } 

        if (digitalRead(ButtonPin2) == LOW) {  
            knop2 = !knop2;
            trillertijd(Triller, 200);
            delay(200);
        } 

        if (digitalRead(ButtonPin3) == LOW) {  
            knop3 = !knop3;
            trillertijd(Triller, 200);
            delay(200);
        } 
        
        if (digitalRead(ButtonPin4) == LOW) {  
            knop4 = !knop4;
            trillertijd(Triller, 200);
            delay(200);
        }    

        if (digitalRead(ButtonPin5) == LOW) {  
            knop5 = !knop5;
            trillertijd(Triller, 200);
            delay(200);
        }
    // wanneer de knoppen aan getoggled zijn dan moet hun lampje respectievelijk branden
        digitalWrite(LedPin1, knop1);
        digitalWrite(LedPin2, knop2);
        digitalWrite(LedPin3, knop3);
        digitalWrite(LedPin4, knop4);
        digitalWrite(LedPin5, knop5);

    // wanneer de verzend knop wordt ingeduwd worden de emoties die aan stonden doorgestuurd en worden ze terug afgezet

        if (digitalRead(ButtonPin6) == LOW) { 
            trillertijd(Triller, 500);

            if (knop1 == true){
                B.println("Knop 1 is ingedrukt!");
                knop1 = !knop1;
            }
            if (knop2 == true){
                B.println("Knop 2 is ingedrukt!");
                knop2 = !knop2;
            }
            if (knop3 == true){
                B.println("Knop 3 is ingedrukt!");
                knop3 = !knop3;
            }
            if (knop4 == true){
                B.println("Knop 4 is ingedrukt!");
                knop4 = !knop4;
            }
            if (knop5 == true){
                B.println("Knop 5 is ingedrukt!");
                knop5 = !knop5;

            }
            
            B.println("Emoties verzonden!");
            delay(200);
        }
        
    }

    if(digitalRead(SwitchPin) == LOW){
        digitalWrite(LedPin1, LOW);
        digitalWrite(LedPin2, LOW);
        digitalWrite(LedPin3, LOW);
        digitalWrite(LedPin4, LOW);
        digitalWrite(LedPin5, LOW);
        
        knop1 = false;
        knop2 = false;
        knop3 = false;
        knop4 = false;
        knop5 = false;

    }
}

```

## code 1 ledje (pinkt 1 maal bij emotieknop, 2 maal verzendknop

```cpp

#include<SoftwareSerial.h>

SoftwareSerial B(10, 11);

int ButtonPin1= 2;
int ButtonPin2= 3;
int ButtonPin3= 4;
int ButtonPin4= 5;
int ButtonPin5= 6;
int ButtonPin6= 7;

int SwitchPin = A3;

const int Sololampje = A5;

bool knop1 = false;
bool knop2 = false;
bool knop3 = false;
bool knop4 = false;
bool knop5 = false;

void setup() {

    B.begin(9600);
    pinMode(ButtonPin1, INPUT_PULLUP);
    pinMode(ButtonPin2, INPUT_PULLUP);
    pinMode(ButtonPin3, INPUT_PULLUP);
    pinMode(ButtonPin4, INPUT_PULLUP);
    pinMode(ButtonPin5, INPUT_PULLUP);
    pinMode(ButtonPin6, INPUT_PULLUP);

    pinMode(SwitchPin, INPUT);

    pinMode(Sololampje, OUTPUT);

}

void trillertijd(int pin, int duur) {
  digitalWrite(pin, HIGH);
  delay(duur);
  digitalWrite(pin, LOW);
}

void loop() {
    
    //digitalWrite(Triller, LOW);   //Startstand triller = low

//  code die enkel gebeurd als de switch werkt
    if(digitalRead(SwitchPin) == HIGH){

    // wanneer 5 emotieknoppen worden ingeduwd veranderd de staat ervan (toggle aan uit)
        if (digitalRead(ButtonPin1) == LOW) {  
            knop1 = !knop1; 
            trillertijd(Sololampje, 200);
            
            delay(200);
        } 

        if (digitalRead(ButtonPin2) == LOW) {  
            knop2 = !knop2;
            trillertijd(Sololampje, 200);
            delay(200);
        } 

        if (digitalRead(ButtonPin3) == LOW) {  
            knop3 = !knop3;
            trillertijd(Sololampje, 200);
            delay(200);
        } 
        
        if (digitalRead(ButtonPin4) == LOW) {  
            knop4 = !knop4;
            trillertijd(Sololampje, 200);
            delay(200);
        }    

        if (digitalRead(ButtonPin5) == LOW) {  
            knop5 = !knop5;
            trillertijd(Sololampje, 200);
            delay(200);
        }

    // wanneer de verzend knop wordt ingeduwd worden de emoties die aan stonden doorgestuurd en worden ze terug afgezet

        if (digitalRead(ButtonPin6) == LOW) { 
            
            trillertijd(Sololampje, 100);
            delay(100);
            trillertijd(Sololampje, 100);

            if (knop1 == true){
                B.println("Knop 1 is ingedrukt!");
                knop1 = !knop1;
            }
            if (knop2 == true){
                B.println("Knop 2 is ingedrukt!");
                knop2 = !knop2;
            }
            if (knop3 == true){
                B.println("Knop 3 is ingedrukt!");
                knop3 = !knop3;
            }
            if (knop4 == true){
                B.println("Knop 4 is ingedrukt!");
                knop4 = !knop4;
            }
            if (knop5 == true){
                B.println("Knop 5 is ingedrukt!");
                knop5 = !knop5;

            }
            
            B.println("Emoties verzonden!");
            delay(200);
        }
        
    }

    if(digitalRead(SwitchPin) == LOW){

        knop1 = false;
        knop2 = false;
        knop3 = false;
        knop4 = false;
        knop5 = false;

    }
}

```

## code triller bij emotieknop, langer trillern bij verzendknop

```cpp

#include<SoftwareSerial.h>

SoftwareSerial B(10, 11);

int ButtonPin1= 2;
int ButtonPin2= 3;
int ButtonPin3= 4;
int ButtonPin4= 5;
int ButtonPin5= 6;
int ButtonPin6= 7;

int SwitchPin = A3;

const int Triller = A4;

bool knop1 = false;
bool knop2 = false;
bool knop3 = false;
bool knop4 = false;
bool knop5 = false;

void setup() {

    B.begin(9600);
    pinMode(ButtonPin1, INPUT_PULLUP);
    pinMode(ButtonPin2, INPUT_PULLUP);
    pinMode(ButtonPin3, INPUT_PULLUP);
    pinMode(ButtonPin4, INPUT_PULLUP);
    pinMode(ButtonPin5, INPUT_PULLUP);
    pinMode(ButtonPin6, INPUT_PULLUP);

    pinMode(SwitchPin, INPUT);

    pinMode(Triller, OUTPUT);

}

void trillertijd(int pin, int duur) {
  digitalWrite(pin, HIGH);
  delay(duur);
  digitalWrite(pin, LOW);
}

void loop() {
    
    //digitalWrite(Triller, LOW);   //Startstand triller = low

//  code die enkel gebeurd als de switch werkt
    if(digitalRead(SwitchPin) == HIGH){

    // wanneer 5 emotieknoppen worden ingeduwd veranderd de staat ervan (toggle aan uit)
        if (digitalRead(ButtonPin1) == LOW) {  
            knop1 = !knop1; 
            trillertijd(Triller, 200);
            
            delay(200);
        } 

        if (digitalRead(ButtonPin2) == LOW) {  
            knop2 = !knop2;
            trillertijd(Triller, 200);
            delay(200);
        } 

        if (digitalRead(ButtonPin3) == LOW) {  
            knop3 = !knop3;
            trillertijd(Triller, 200);
            delay(200);
        } 
        
        if (digitalRead(ButtonPin4) == LOW) {  
            knop4 = !knop4;
            trillertijd(Triller, 200);
            delay(200);
        }    

        if (digitalRead(ButtonPin5) == LOW) {  
            knop5 = !knop5;
            trillertijd(Triller, 200);
            delay(200);
        }

    // wanneer de verzend knop wordt ingeduwd worden de emoties die aan stonden doorgestuurd en worden ze terug afgezet

        if (digitalRead(ButtonPin6) == LOW) { 
            trillertijd(Triller, 500);
            
            if (knop1 == true){
                B.println("Knop 1 is ingedrukt!");
                knop1 = !knop1;
            }
            if (knop2 == true){
                B.println("Knop 2 is ingedrukt!");
                knop2 = !knop2;
            }
            if (knop3 == true){
                B.println("Knop 3 is ingedrukt!");
                knop3 = !knop3;
            }
            if (knop4 == true){
                B.println("Knop 4 is ingedrukt!");
                knop4 = !knop4;
            }
            if (knop5 == true){
                B.println("Knop 5 is ingedrukt!");
                knop5 = !knop5;

            }
            
            B.println("Emoties verzonden!");
            delay(200);
        }
        
    }

    if(digitalRead(SwitchPin) == LOW){
             
        knop1 = false;
        knop2 = false;  
        knop3 = false;
        knop4 = false;
        knop5 = false;

    }
}
```

## code versie 5 - on off switch - ledjes bij elke emotieknop

```cpp

#include<SoftwareSerial.h>

SoftwareSerial B(10, 11);

int ButtonPin1= 2;
int ButtonPin2= 3;
int ButtonPin3= 4;
int ButtonPin4= 5;
int ButtonPin5= 6;
int ButtonPin6= 7;

int LedPin1 = A1;
int LedPin2 = 8;
int LedPin3 = 9;
int LedPin4 = 12;
int LedPin5 = 13;

int SwitchPin = A3;

bool knop1 = false;
bool knop2 = false;
bool knop3 = false;
bool knop4 = false;
bool knop5 = false;

void setup() {

    B.begin(9600);
    pinMode(ButtonPin1, INPUT_PULLUP);
    pinMode(ButtonPin2, INPUT_PULLUP);
    pinMode(ButtonPin3, INPUT_PULLUP);
    pinMode(ButtonPin4, INPUT_PULLUP);
    pinMode(ButtonPin5, INPUT_PULLUP);
    pinMode(ButtonPin6, INPUT_PULLUP);

    pinMode(SwitchPin, INPUT);

    pinMode(LedPin1, OUTPUT);
    pinMode(LedPin2, OUTPUT);
    pinMode(LedPin3, OUTPUT);
    pinMode(LedPin4, OUTPUT);
    pinMode(LedPin5, OUTPUT);
}

void loop() {
//  code die enkel gebeurd als de switch werkt
    if(digitalRead(SwitchPin) == HIGH){

    // wanneer 5 emotieknoppen worden ingeduwd veranderd de staat ervan (toggle aan uit)
        if (digitalRead(ButtonPin1) == LOW) {  
            knop1 = !knop1; 
            //B.println("Knop 1 is ingedrukt!");
            delay(200);
        } 

        if (digitalRead(ButtonPin2) == LOW) {  
            knop2 = !knop2;
            //B.println("Knop 2 is ingedrukt!");
            delay(200);
        } 

        if (digitalRead(ButtonPin3) == LOW) {  
            knop3 = !knop3;
            //B.println("Knop 3 is ingedrukt!");
            delay(200);
        } 
        
        if (digitalRead(ButtonPin4) == LOW) {  
            knop4 = !knop4;
            //B.println("Knop 4 is ingedrukt!");
            delay(200);
        }    

        if (digitalRead(ButtonPin5) == LOW) {  
            knop5 = !knop5;
            //B.println("Knop 5 is ingedrukt!");
            delay(200);
        }
    // wanneer de knoppen aan getoggled zijn dan moet hun lampje respectievelijk branden
        digitalWrite(LedPin1, knop1);
        digitalWrite(LedPin2, knop2);
        digitalWrite(LedPin3, knop3);
        digitalWrite(LedPin4, knop4);
        digitalWrite(LedPin5, knop5);

    // wanneer de verzend knop wordt ingeduwd worden de emoties die aan stonden doorgestuurd en worden ze terug afgezet

        if (digitalRead(ButtonPin6) == LOW) {  
            if (knop1 == true){
                B.println("Knop 1 is ingedrukt!");
                knop1 = !knop1;
            }
            if (knop2 == true){
                B.println("Knop 2 is ingedrukt!");
                knop2 = !knop2;
            }
            if (knop3 == true){
                B.println("Knop 3 is ingedrukt!");
                knop3 = !knop3;
            }
            if (knop4 == true){
                B.println("Knop 4 is ingedrukt!");
                knop4 = !knop4;
            }
            if (knop5 == true){
                B.println("Knop 5 is ingedrukt!");
                knop5 = !knop5;

            }
            
            B.println("Emoties verzonden!");
            delay(200);
        }
        
    }

    if(digitalRead(SwitchPin) == LOW){
        digitalWrite(LedPin1, LOW);
        digitalWrite(LedPin2, LOW);
        digitalWrite(LedPin3, LOW);
        digitalWrite(LedPin4, LOW);
        digitalWrite(LedPin5, LOW);
        knop1 = false;
        knop2 = false;
        knop3 = false;
        knop4 = false;
        knop5 = false;

    }
}

```



## code versie 4 (test of switch werkt)

```cpp

#include<SoftwareSerial.h>

SoftwareSerial B(10, 11);

int ButtonPin1= 2;
int ButtonPin2= 3;
int ButtonPin3= 4;
int ButtonPin4= 5;
int ButtonPin5= 6;
int ButtonPin6= 7;

int LedPin1 = A1;
int LedPin2 = 8;
int LedPin3 = 9;
int LedPin4 = 12;
int LedPin5 = 13;

int SwitchPin = A3;

bool knop1 = false;
bool knop2 = false;
bool knop3 = false;
bool knop4 = false;
bool knop5 = false;

void setup() {

    B.begin(9600);
    pinMode(ButtonPin1, INPUT_PULLUP);
    pinMode(ButtonPin2, INPUT_PULLUP);
    pinMode(ButtonPin3, INPUT_PULLUP);
    pinMode(ButtonPin4, INPUT_PULLUP);
    pinMode(ButtonPin5, INPUT_PULLUP);
    pinMode(ButtonPin6, INPUT_PULLUP);

    pinMode(SwitchPin, INPUT);

    pinMode(LedPin1, OUTPUT);
    pinMode(LedPin2, OUTPUT);
    pinMode(LedPin3, OUTPUT);
    pinMode(LedPin4, OUTPUT);
    pinMode(LedPin5, OUTPUT);
}

void loop() {
//  code die kijkt of de switch werkt
    if(digitalRead(SwitchPin) == HIGH){
        B.println("AAN");
        delay(200);
    }

// wanneer 5 emotieknoppen worden ingeduwd veranderd de staat ervan (toggle aan uit)
    if (digitalRead(ButtonPin1) == LOW) {  
        knop1 = !knop1; 
        //B.println("Knop 1 is ingedrukt!");
        delay(200);
    } 

    if (digitalRead(ButtonPin2) == LOW) {  
        knop2 = !knop2;
        //B.println("Knop 2 is ingedrukt!");
        delay(200);
    } 

    if (digitalRead(ButtonPin3) == LOW) {  
        knop3 = !knop3;
        //B.println("Knop 3 is ingedrukt!");
        delay(200);
    } 
    
    if (digitalRead(ButtonPin4) == LOW) {  
        knop4 = !knop4;
        //B.println("Knop 4 is ingedrukt!");
        delay(200);
    }    

    if (digitalRead(ButtonPin5) == LOW) {  
        knop5 = !knop5;
        //B.println("Knop 5 is ingedrukt!");
        delay(200);
    }
// wanneer de knoppen aan getoggled zijn dan moet hun lampje respectievelijk branden
    digitalWrite(LedPin1, knop1);
    digitalWrite(LedPin2, knop2);
    digitalWrite(LedPin3, knop3);
    digitalWrite(LedPin4, knop4);
    digitalWrite(LedPin5, knop5);

// wanneer de verzend knop wordt ingeduwd worden de emoties die aan stonden doorgestuurd en worden ze terug afgezet

    if (digitalRead(ButtonPin6) == LOW) {  
        if (knop1 == true){
            B.println("Knop 1 is ingedrukt!");
            knop1 = !knop1;
        }
        if (knop2 == true){
            B.println("Knop 2 is ingedrukt!");
            knop2 = !knop2;
        }
        if (knop3 == true){
            B.println("Knop 3 is ingedrukt!");
            knop3 = !knop3;
        }
        if (knop4 == true){
            B.println("Knop 4 is ingedrukt!");
            knop4 = !knop4;
        }
        if (knop5 == true){
            B.println("Knop 5 is ingedrukt!");
            knop5 = !knop5;

        }
        
        B.println("Emoties verzonden!");
        delay(200);
    }
    
}

```

## code versie 3

```cpp

#include<SoftwareSerial.h>

SoftwareSerial B(10, 11);

int ButtonPin1= 2;
int ButtonPin2= 3;
int ButtonPin3= 4;
int ButtonPin4= 5;
int ButtonPin5= 6;
int ButtonPin6= 7;

int LedPin1 = 1;
int LedPin2 = 8;
int LedPin3 = 9;
int LedPin4 = 12;
int LedPin5 = 13;

bool knop1 = false;
bool knop2 = false;
bool knop3 = false;
bool knop4 = false;
bool knop5 = false;

void setup() {

    B.begin(9600);
    pinMode(ButtonPin1, INPUT_PULLUP);
    pinMode(ButtonPin2, INPUT_PULLUP);
    pinMode(ButtonPin3, INPUT_PULLUP);
    pinMode(ButtonPin4, INPUT_PULLUP);
    pinMode(ButtonPin5, INPUT_PULLUP);
    pinMode(ButtonPin6, INPUT_PULLUP);

    pinMode(LedPin1, OUTPUT);
    pinMode(LedPin2, OUTPUT);
    pinMode(LedPin3, OUTPUT);
    pinMode(LedPin4, OUTPUT);
    pinMode(LedPin5, OUTPUT);
}

void loop() {

// wanneer 5 emotieknoppen worden ingeduwd veranderd de staat ervan (toggle aan uit)
    if (digitalRead(ButtonPin1) == LOW) {  
        knop1 = !knop1; 
        //B.println("Knop 1 is ingedrukt!");
        delay(200);
    } 

    if (digitalRead(ButtonPin2) == LOW) {  
        knop2 = !knop2;
        //B.println("Knop 2 is ingedrukt!");
        delay(200);
    } 

    if (digitalRead(ButtonPin3) == LOW) {  
        knop3 = !knop3;
        //B.println("Knop 3 is ingedrukt!");
        delay(200);
    } 
    
    if (digitalRead(ButtonPin4) == LOW) {  
        knop4 = !knop4;
        //B.println("Knop 4 is ingedrukt!");
        delay(200);
    }    

    if (digitalRead(ButtonPin5) == LOW) {  
        knop5 = !knop5;
        //B.println("Knop 5 is ingedrukt!");
        delay(200);
    }
// wanneer de knoppen aan getoggled zijn dan moet hun lampje respectievelijk branden
    digitalWrite(LedPin1, knop1);
    digitalWrite(LedPin2, knop2);
    digitalWrite(LedPin3, knop3);
    digitalWrite(LedPin4, knop4);
    digitalWrite(LedPin5, knop5);

// wanneer de verzend knop wordt ingeduwd worden de emoties die aan stonden doorgestuurd en worden ze terug afgezet

    if (digitalRead(ButtonPin6) == LOW) {  
        if (knop1 == true){
            B.println("Knop 1 is ingedrukt!");
            knop1 = !knop1;
        }
        if (knop2 == true){
            B.println("Knop 2 is ingedrukt!");
            knop2 = !knop2;
        }
        if (knop3 == true){
            B.println("Knop 3 is ingedrukt!");
            knop3 = !knop3;
        }
        if (knop4 == true){
            B.println("Knop 4 is ingedrukt!");
            knop4 = !knop4;
        }
        if (knop5 == true){
            B.println("Knop 5 is ingedrukt!");
            knop5 = !knop5;

        }
        
        B.println("Emoties verzonden!");
        delay(200);
    }
    
}

```



## code versie 2

```cpp

#include<SoftwareSerial.h>

SoftwareSerial B(10, 11);

int ButtonPin1= 2;
int ButtonPin2= 3;
int ButtonPin3= 4;
int ButtonPin4= 5;
int ButtonPin5= 6;
int ButtonPin6= 7;

bool knop1 = false;
bool knop2 = false;
bool knop3 = false;
bool knop4 = false;
bool knop5 = false;

void setup() {

  B.begin(9600);
  pinMode(ButtonPin1, INPUT_PULLUP);
  pinMode(ButtonPin2, INPUT_PULLUP);
  pinMode(ButtonPin3, INPUT_PULLUP);
  pinMode(ButtonPin4, INPUT_PULLUP);
  pinMode(ButtonPin5, INPUT_PULLUP);
  pinMode(ButtonPin6, INPUT_PULLUP);

}

void loop() {

    if (digitalRead(ButtonPin1) == LOW) {  
        knop1 = !knop1; 
        //B.println("Knop 1 is ingedrukt!");
        delay(200);
    } 

    if (digitalRead(ButtonPin2) == LOW) {  
        knop2 = !knop2;
        //B.println("Knop 2 is ingedrukt!");
        delay(200);
    } 

    if (digitalRead(ButtonPin3) == LOW) {  
        knop3 = !knop3;
        //B.println("Knop 3 is ingedrukt!");
        delay(200);
    } 
    
    if (digitalRead(ButtonPin4) == LOW) {  
        knop4 = !knop4;
        //B.println("Knop 4 is ingedrukt!");
        delay(200);
    }    

    if (digitalRead(ButtonPin5) == LOW) {  
        knop5 = !knop5;
        //B.println("Knop 5 is ingedrukt!");
        delay(200);
    }

    if (digitalRead(ButtonPin6) == LOW) {  
        if (knop1 == true){
            B.println("Knop 1 is ingedrukt!");
            knop1 = !knop1;
        }
        if (knop2 == true){
            B.println("Knop 2 is ingedrukt!");
            knop2 = !knop2;
        }
        if (knop3 == true){
            B.println("Knop 3 is ingedrukt!");
            knop3 = !knop3;
        }
        if (knop4 == true){
            B.println("Knop 4 is ingedrukt!");
            knop4 = !knop4;
        }
        if (knop5 == true){
            B.println("Knop 5 is ingedrukt!");
            knop5 = !knop5;

        }
        
        B.println("Emoties verzonden!");
        delay(200);
    }
    
}

```



## code versie 1 

```cpp

#include<SoftwareSerial.h>

SoftwareSerial B(10, 11);

int ButtonPin1= 2;
int ButtonPin2= 3;

void setup() {

  B.begin(9600);
  pinMode(ButtonPin1, INPUT_PULLUP);
  pinMode(ButtonPin2, INPUT_PULLUP);

}

void loop() {
    
    if (digitalRead(ButtonPin1) == LOW) {  
        
        B.println("Knop 1 is ingedrukt!");
        delay(200);
    }    
    if (digitalRead(ButtonPin2) == LOW) {  
        
        B.println("Knop 2 is ingedrukt!");
        delay(200);
    }
    
}

```



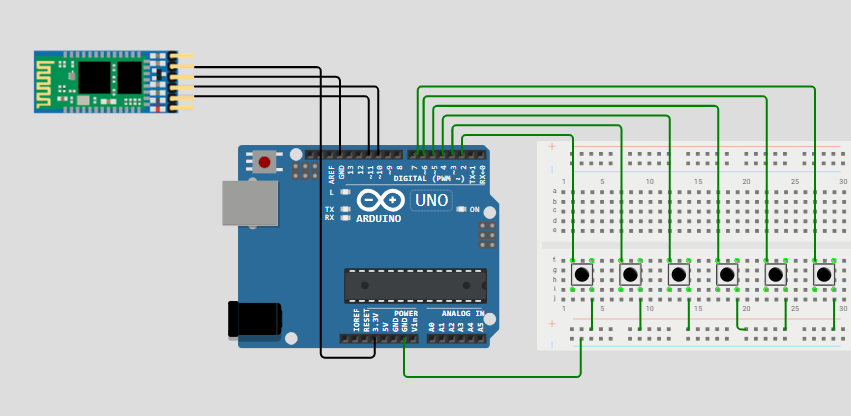
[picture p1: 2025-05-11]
images/versie 2 schema.png

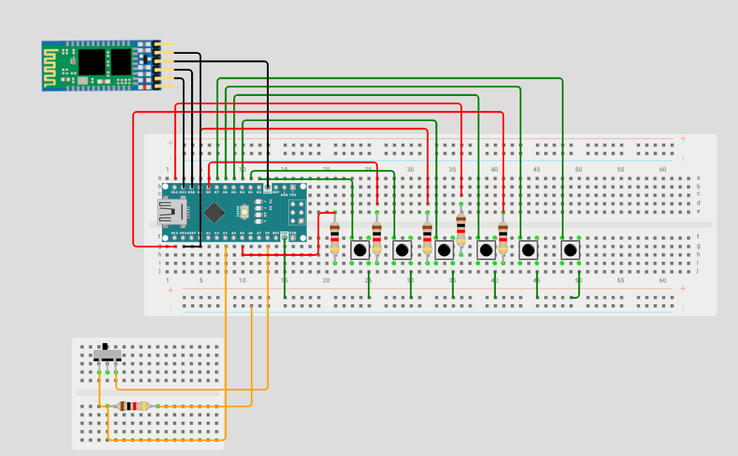
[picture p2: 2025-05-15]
images/versie 10 schema.png

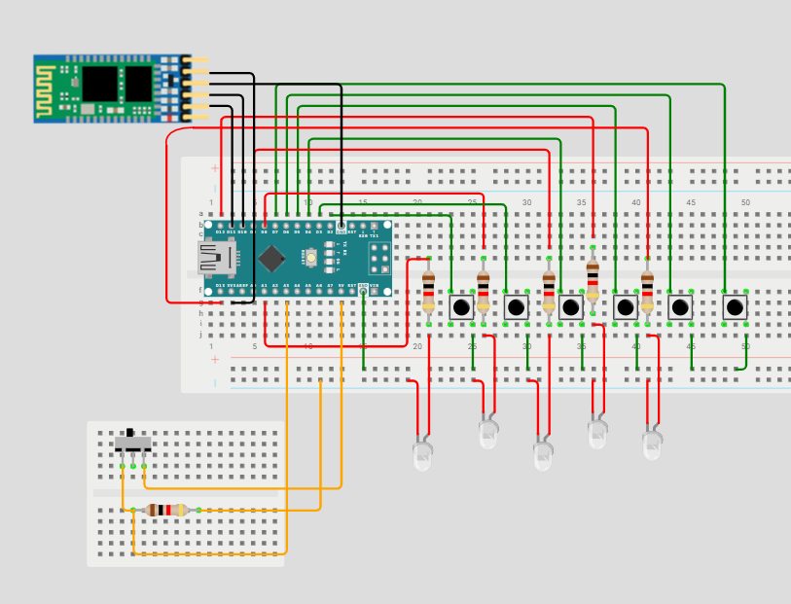
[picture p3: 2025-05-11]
images/versie 5 schema.png

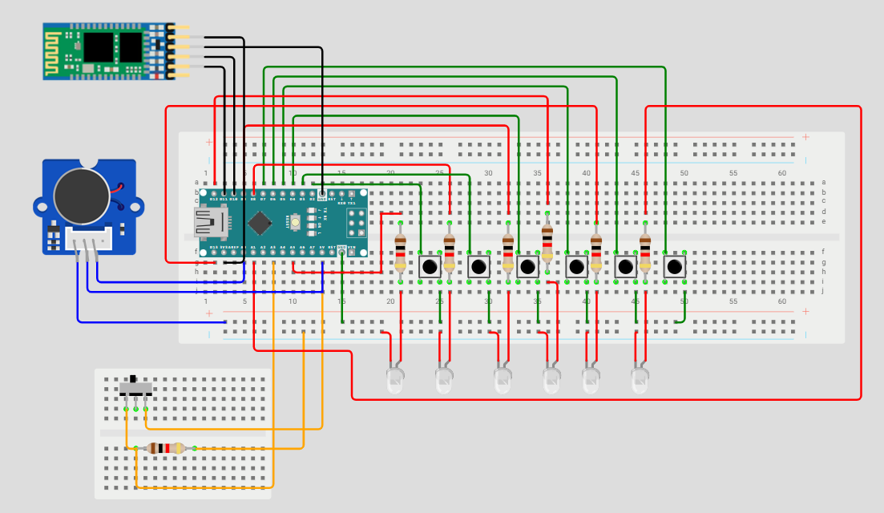
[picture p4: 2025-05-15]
images/versie finaal schema.png

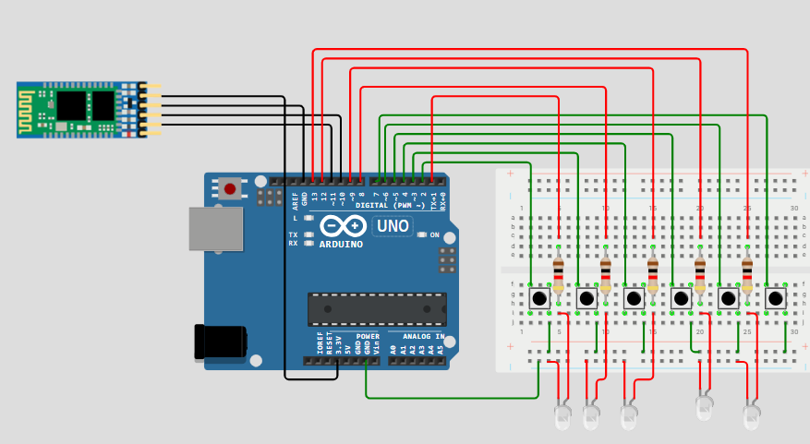
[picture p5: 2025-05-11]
images/versie 3 schema.png

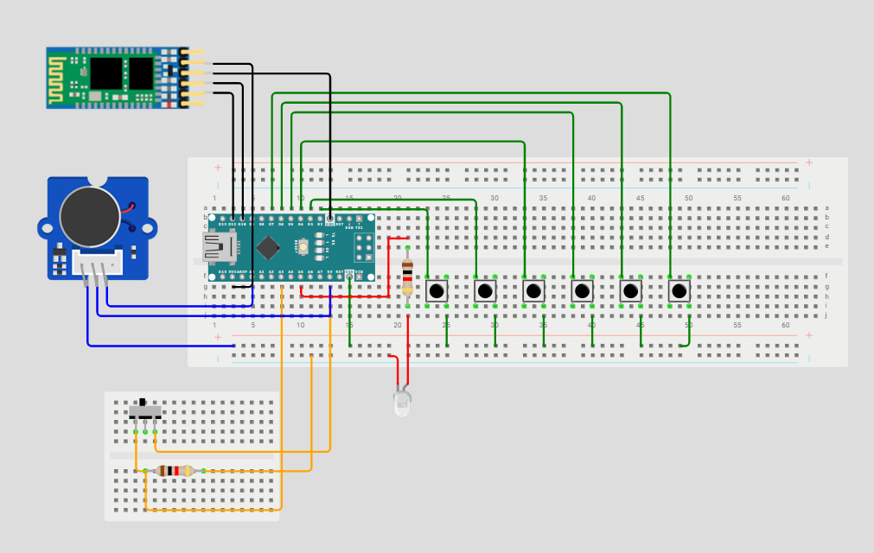
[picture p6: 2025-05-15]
images/versie 9 schema.png

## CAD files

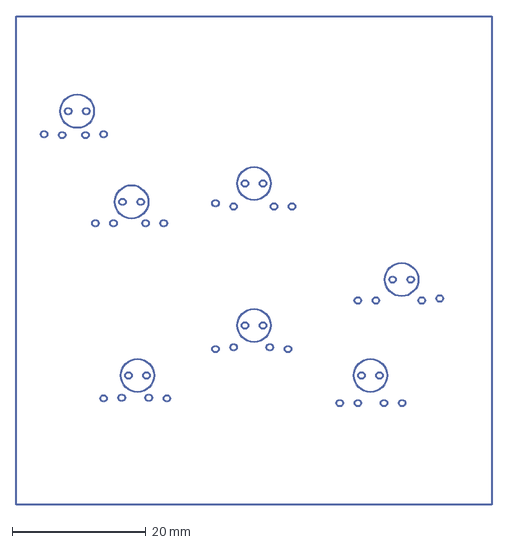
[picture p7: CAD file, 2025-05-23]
BillOfMaterials/electronica/plaatje weerstanden.dxf
71.0 x 73.0 mm

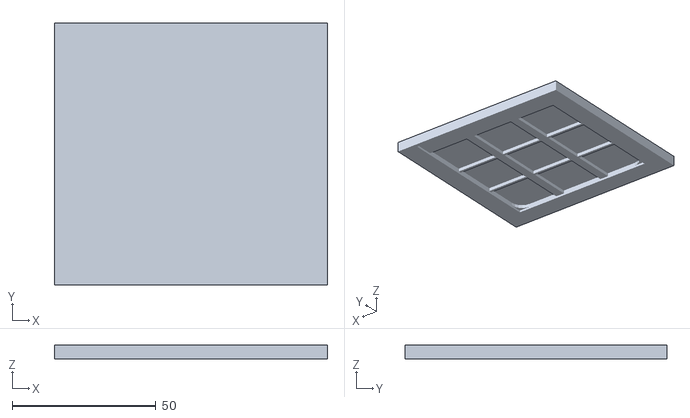
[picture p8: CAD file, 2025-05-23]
BillOfMaterials/feellink onderdelen/mold textuur.stl
95.0 x 91.0 x 5.00

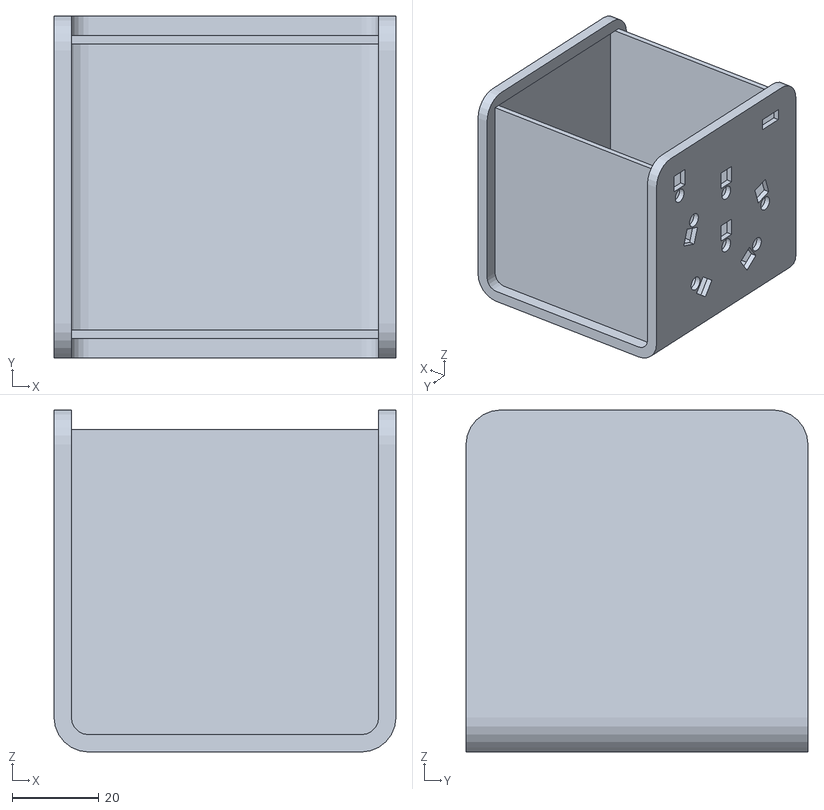
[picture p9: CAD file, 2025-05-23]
BillOfMaterials/feellink onderdelen/deel 1 feellink.stl
79.0 x 79.0 x 79.0

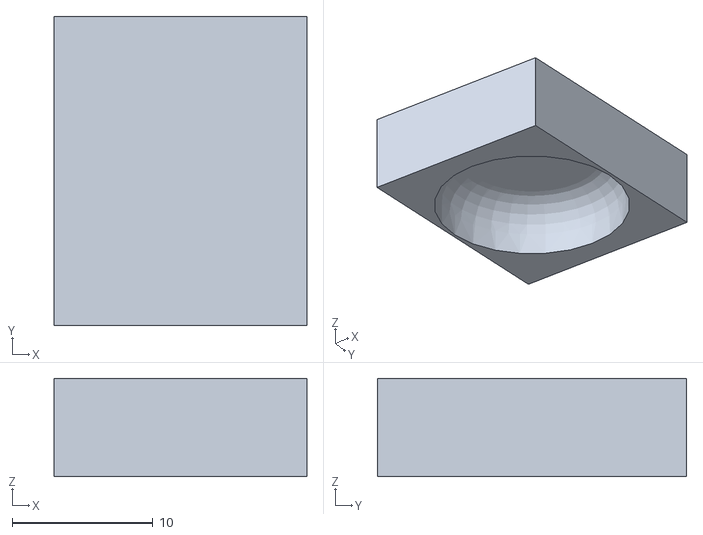
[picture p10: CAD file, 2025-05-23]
BillOfMaterials/feellink onderdelen/knoppen mold.stl
18.0 x 22.0 x 7.00

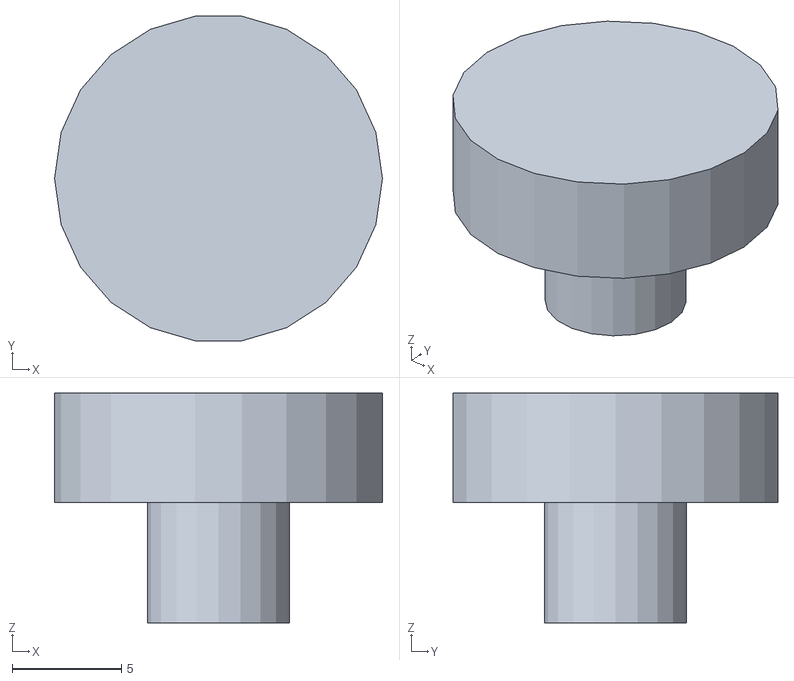
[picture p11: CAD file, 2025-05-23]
BillOfMaterials/feellink onderdelen/draaielement 2.stl
15.0 x 14.8 x 10.5

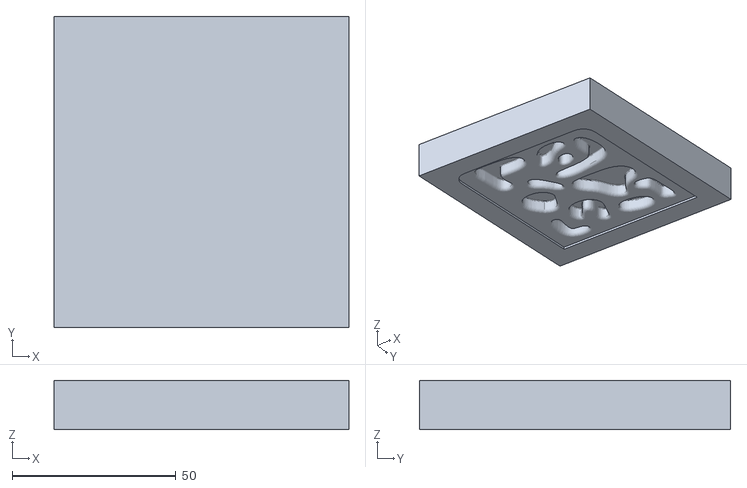
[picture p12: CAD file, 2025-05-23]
BillOfMaterials/feellink onderdelen/squeeze mold.stl
90.0 x 95.0 x 15.0

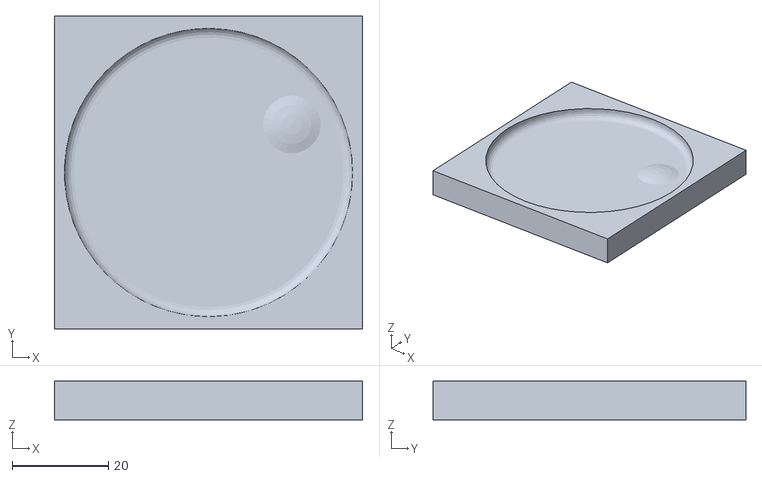
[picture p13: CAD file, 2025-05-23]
BillOfMaterials/feellink onderdelen/draaielement mold.stl
64.0 x 65.0 x 8.00

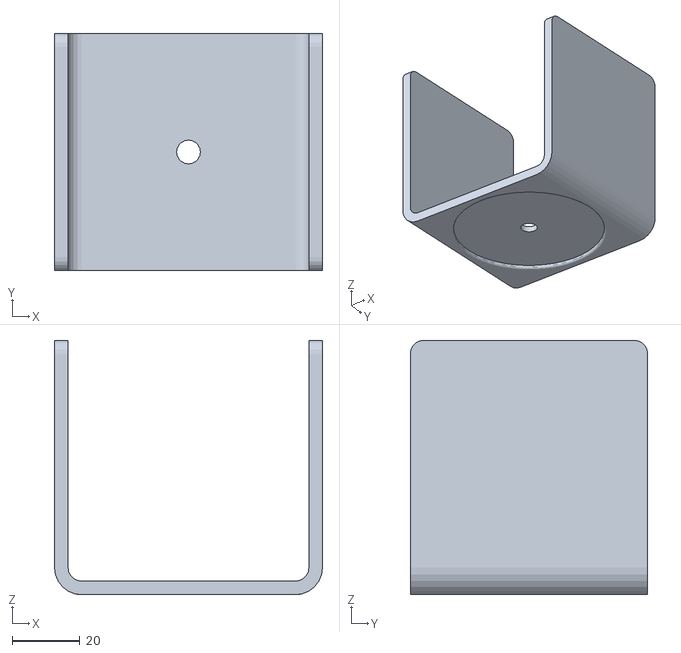
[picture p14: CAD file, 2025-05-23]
BillOfMaterials/feellink onderdelen/deel 2 feellink.stl
79.0 x 70.0 x 75.0
